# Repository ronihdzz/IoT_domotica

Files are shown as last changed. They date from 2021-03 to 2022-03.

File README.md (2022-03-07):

<hr>

## **Sistemas de domótica**
#### Autor: David Roni Hernández Beltrán
<hr>

Explicación del proyecto en español:

(https://www.youtube.com/watch?v=UfCgMUs2OLo)

Explicación del proyecto en ingles:

(https://www.youtube.com/watch?v=xrW_T7PZulM)

### **Menu**

* [1) Prerrequisitos](#1-prerrequisitos)
    * [1.1) Materiales](#11-materiales)
    * [1.2) Instalacion de paquetes de python](#12-instalacion-de-paquetes-de-python)

* [2) Funcionamiento](#2-funcionamiento)

    * [2.0) Explicacion detallada](PlaneacionSistemaDomotica.pdf)
    * [2.1) Explicacion breve](#21-explicacion-breve)
    * [2.2) Explicacion del sofware del proyecto](#22-explicacion-del-sofware-del-proyecto)
        * [2.2.1) Sistema de deberes](#221-sistema-de-deberes)
          * [2.2.1.1) Crear un deber](#2211-crear-un-deber)
          * [2.2.1.2) Cambiar el tamano y la posicion del texto de los deberes](#2212-cambiar-el-tamano-y-la-posicion-del-texto-de-los-deberes)
          * [2.2.1.3) Eliminar deberes cumplidos](#2213-eliminar-deberes-cumplidos)

        * [2.2.2) Sistema de administracion de alarmas](#222-sistema-de-administracion-de-alarmas)
          * [2.2.2.1) Crear una alarma](#2221-crear-una-alarma)
          * [2.2.2.2) Editar una alarma](#2222-editar-una-alarma)
          * [2.2.2.3) Eliminar una alarma](#2223-eliminar-una-alarma)
          * [2.2.2.4) Desactivar y activar una alarma](#2224-desactivar-y-activar-una-alarma)
          * [2.2.2.5) Hora de sonar de la alarma](#2225-hora-de-sonar-de-la-alarma)
          * [2.2.2.6) Establecer una cancion de tu elecccion en una alarma](#2226-establecer-una-cancion-de-tu-elecccion-en-una-alarma)

        * [2.2.3) Sistema de control](#223-sistema-de-control)
          * [2.2.3.1) Ver el dia la hora y la temperatura](#2231-ver-el-dia-la-hora-y-la-temperatura)
          * [2.2.3.2) Prendido manual y automatico de los objetos led RGB y ventilador](#2232-prendido-manual-y-automatico-de-los-objetos-led-rgb-y-ventilador)
            * [2.2.3.2.1) Funcionamiento del control manual y control automatico](#22321-funcionamiento-del-control-manual-y-control-automatico)
            * [2.2.3.2.2) Restricciones del control manual y control automatico](#22322-restricciones-del-control-manual-y-control-automatico)
            * [2.2.3.2.3) Prender y apagar manualmente el led RGB](#22323-prender-y-apagar-manualmente-el-led-rgb)
            * [2.2.3.2.4) Prender y apagar manualmente el ventilador](#22324-prender-y-apagar-manualmente-el-ventilador)
            * [2.2.3.2.5) Prender y apagar automaticamente el led RGB](#22325-prender-y-apagar-automaticamente-el-led-rgb)
            * [2.2.3.2.6) Prender y apagar automaticamente el ventilador](#22326-prender-y-apagar-automaticamente-el-ventilador)
          * [2.2.3.3) Cambiar el color del led RGB](#2233-cambiar-el-color-del-led-rgb)
          * [2.2.3.4) Detector de incendios](#2234-detector-de-incendios)

        * [2.2.4) Datos del programador](#224-datos-del-programador)

    * [2.3) Circuitos del proyecto](#23-circuitos-del-proyecto)

* [3) Ensamble del proyecto](#3-ensamble-del-proyecto)
    * [3.1) Paso 1](#31-paso-1)
    * [3.2) Paso 2](#32-paso-2)
    * [3.3) Paso 3](#33-paso-3)
    * [3.4) Paso 4](#34-paso-4)
    * [3.5) Paso 5](#35-paso-5)
    * [3.6) Paso 6(opccional)](#36-paso-6opccional)

* [4) Posibles errores](#4-posibles-errores)

* [5) Fuentes de informacion](#5-fuentes-de-informacion)

<hr>

## **1) Prerrequisitos**
<div class="myWrapper" markdown="1" align="center">

[Regresar al menu principal](#menu)
</div>

<hr>

A continuación se enlistan los prerrequisitos para poder ejecutar el proyecto:

### **1.1) Materiales**
<div class="myWrapper" markdown="1" align="center">

[Regresar al menu principal](#menu)
</div>

* 1-. Una computadora o...
  * Una rasberry pi y una monitor
  * Una rasberry pi y una tablet
  * Una rasberry pi y celular

<!--style="margin-left:auto;margin-right:auto;width:100%;"-->
<div style="text-align: center;">
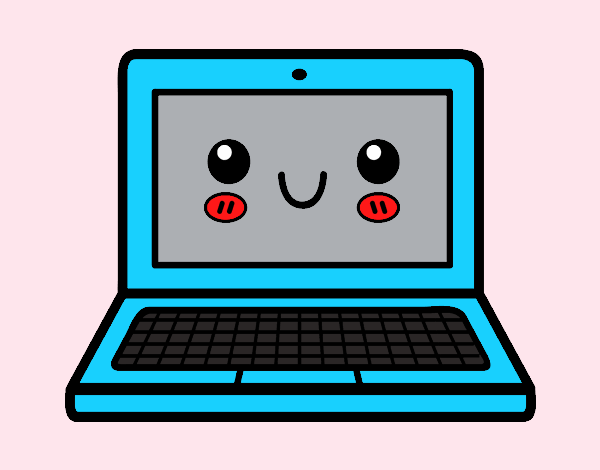
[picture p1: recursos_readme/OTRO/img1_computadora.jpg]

</div>

<!--style="margin-left:auto;margin-right:auto;width:100%;"-->
<div style="text-align: center;">
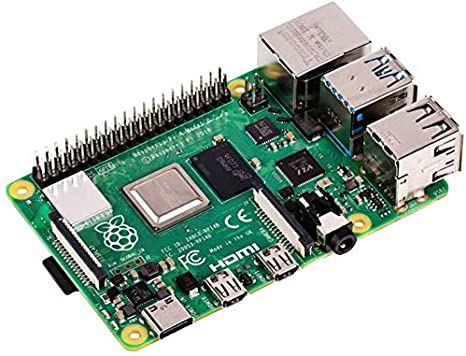
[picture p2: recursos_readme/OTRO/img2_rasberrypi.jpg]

</div>

* 2-. Un modulo adaptador serie usb a serial, yo recomiendo el: **convertidor USB Serial FTDI TTL FT232R**

<!--style="margin-left:auto;margin-right:auto;width:100%;"-->
<div style="text-align: center;">
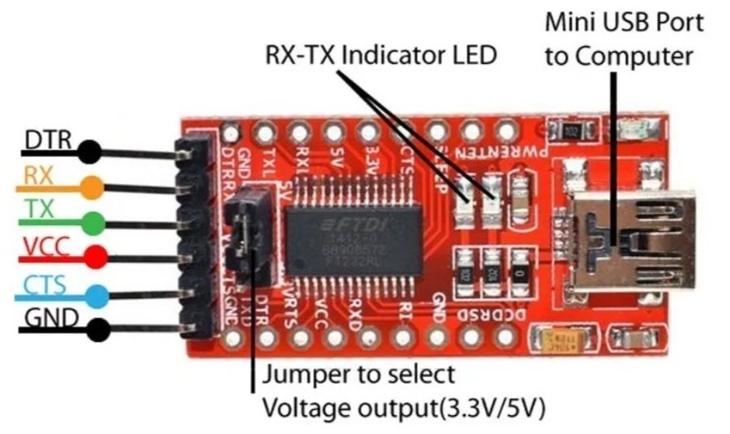
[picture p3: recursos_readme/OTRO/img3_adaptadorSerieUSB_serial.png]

</div>

* 3-. Un modulo bluetooth hc-05

<!--style="margin-left:auto;margin-right:auto;width:100%;"-->
<div style="text-align: center;">
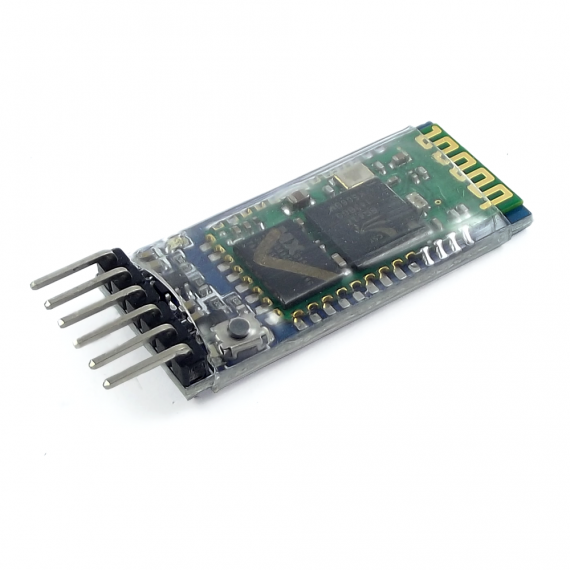
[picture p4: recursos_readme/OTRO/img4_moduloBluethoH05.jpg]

</div>

* 4-. Un cable USB a mini USB( para conectar el adaptador convertidor USB Serial FTDI TTL FT232R a un puerto usb de la rasberry o un puerto usb de la  computadora)
<!--style="margin-left:auto;margin-right:auto;width:100%;"-->
<div style="text-align: center;">
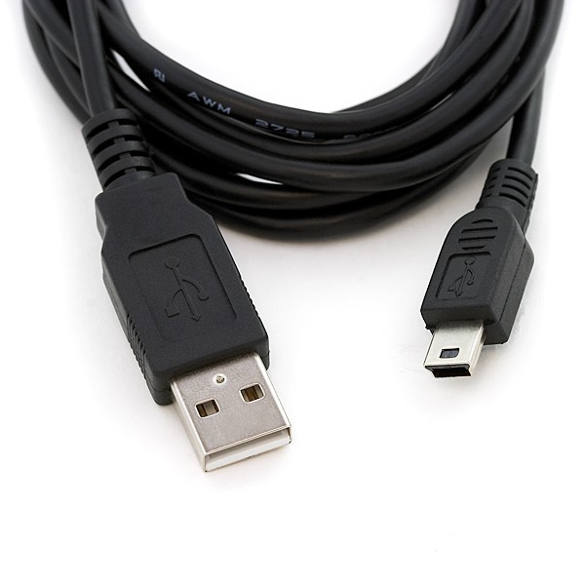
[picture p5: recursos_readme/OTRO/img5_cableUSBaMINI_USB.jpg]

</div>

* 5-. Un led RGB de preferencia el **sensor led RGB módulo KY-016**

<!--style="margin-left:auto;margin-right:auto;width:100%;"-->
<div style="text-align: center;">
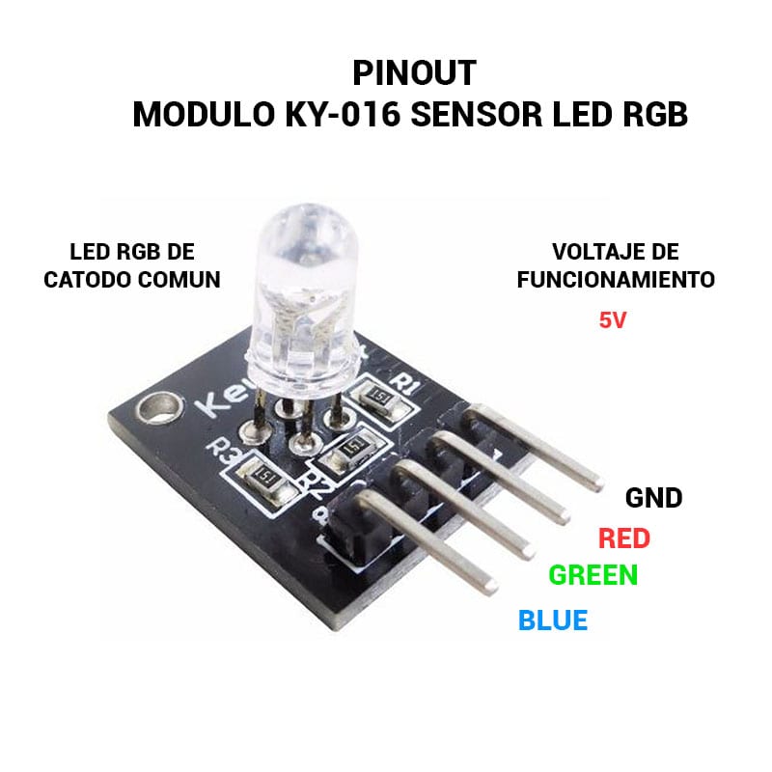
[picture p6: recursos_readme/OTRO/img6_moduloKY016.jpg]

</div>

* 6-. Un sensor de temperatura módulo KY-013

<!--style="margin-left:auto;margin-right:auto;width:100%;"-->
<div style="text-align: center;">
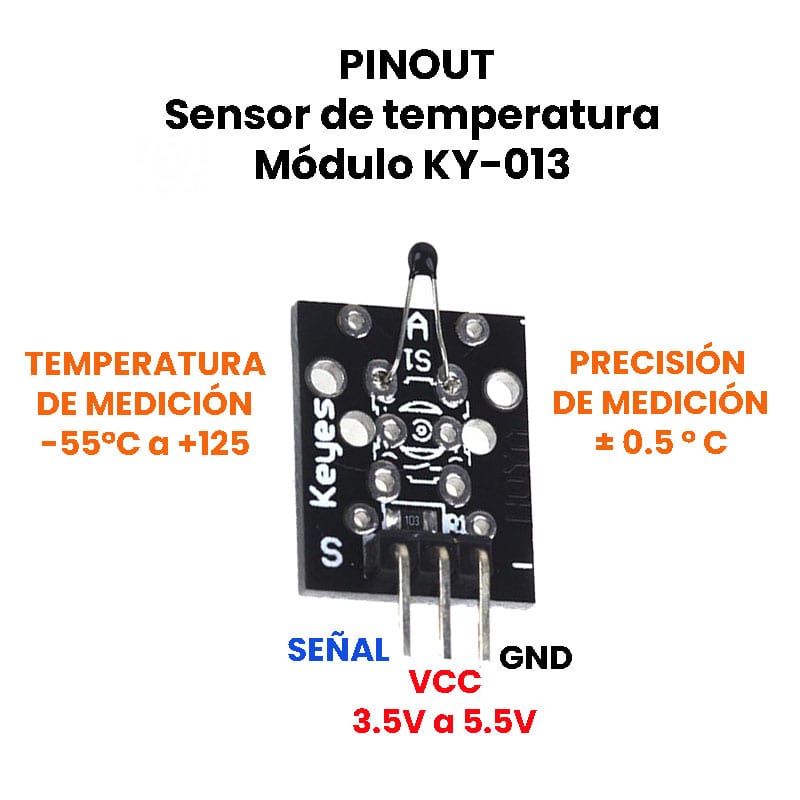
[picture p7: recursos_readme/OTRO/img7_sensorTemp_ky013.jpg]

</div>

* 7-. Un sensor de flama módulo KY-026 

<!--style="margin-left:auto;margin-right:auto;width:100%;"-->
<div style="text-align: center;">
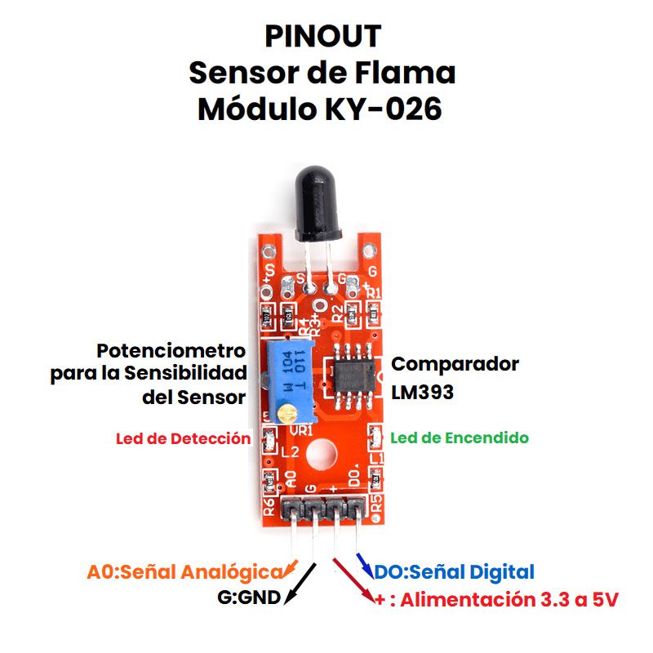
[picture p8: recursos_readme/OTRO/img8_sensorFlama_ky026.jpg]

</div>

* 8-. Un sensor de sonido módulo KY-037 

<!--style="margin-left:auto;margin-right:auto;width:100%;"-->
<div style="text-align: center;">
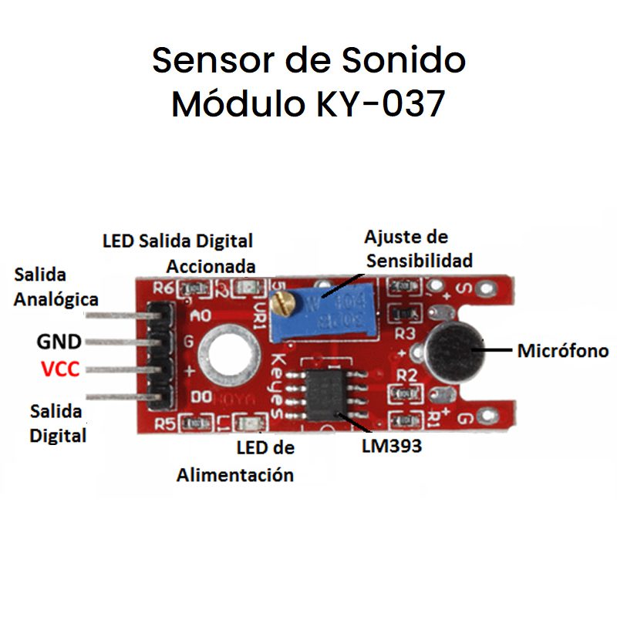
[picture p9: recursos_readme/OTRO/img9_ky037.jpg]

</div>

* 9-. Un módulo relevador 5V KY-019

<!--style="margin-left:auto;margin-right:auto;width:100%;"-->
<div style="text-align: center;">
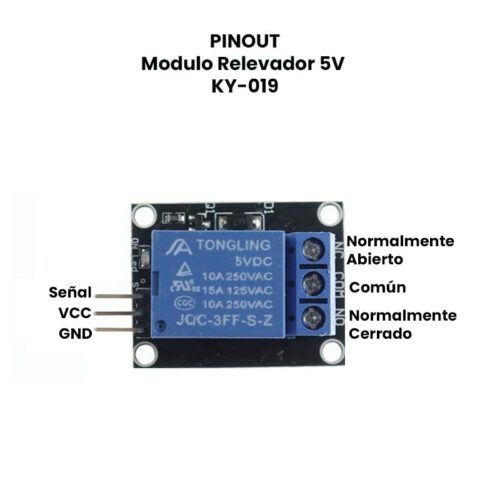
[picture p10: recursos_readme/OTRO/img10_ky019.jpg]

</div>

* 10-. Un arduino nano con su cable

<!--style="margin-left:auto;margin-right:auto;width:100%;"-->
<div style="text-align: center;">
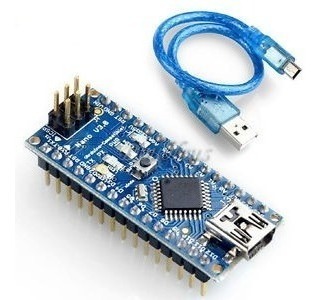
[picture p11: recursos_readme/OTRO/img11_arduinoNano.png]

</div>

* 11-. Un esp-32 nodemcu Micro Usb

<!--style="margin-left:auto;margin-right:auto;width:100%;"-->
<div style="text-align: center;">
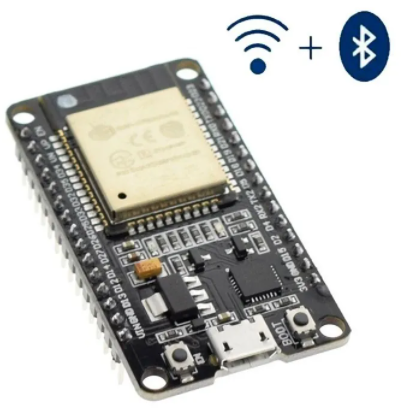
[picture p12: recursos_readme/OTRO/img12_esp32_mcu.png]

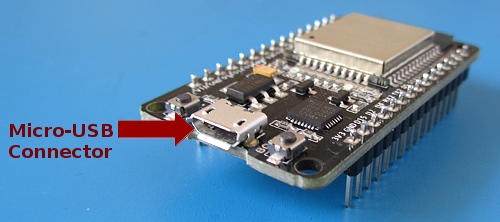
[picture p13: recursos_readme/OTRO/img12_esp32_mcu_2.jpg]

</div>

* 12-. Un cargador de celular con 5 volts de salida y minimo 1 A de corriente cuyo cable tambien permita la transmisión de datos  (para alimentar al esp32 y cargar los programas)

<!--style="margin-left:auto;margin-right:auto;width:100%;"-->
<div style="text-align: center;">
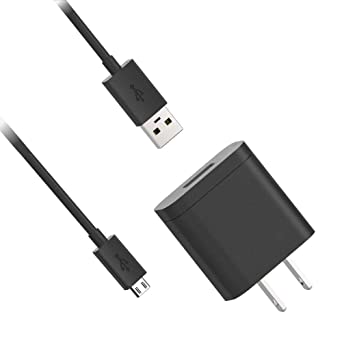
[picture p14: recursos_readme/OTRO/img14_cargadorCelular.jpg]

</div>

* 13-. Alambre de diferentes colores calibre 22(para conexiones en la protoboard) o jumpers macho, pero preferiblemente alambres

<!--style="margin-left:auto;margin-right:auto;width:100%;"-->
<div style="text-align: center;">
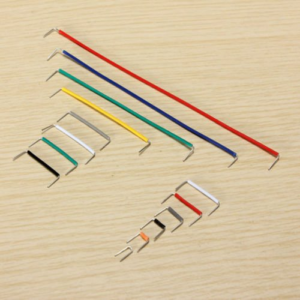
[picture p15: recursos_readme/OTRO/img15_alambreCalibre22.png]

</div>

* 14-. Dos protoboards

<!--style="margin-left:auto;margin-right:auto;width:100%;"-->
<div style="text-align: center;">
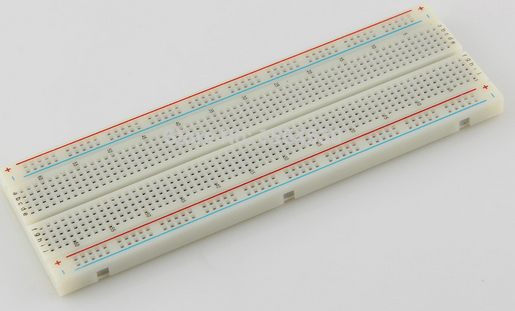
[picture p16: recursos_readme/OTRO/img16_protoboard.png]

</div>

<hr>

### **1.2) Instalacion de paquetes de python**
<div class="myWrapper" markdown="1" align="center">

[Regresar al menu principal](#menu)
</div>

<hr>

Sofware que debera tener instalado la rasberry pi o la computadora:

  * Python 3 instalado 
  * La herramienta de gestión de paquetes pip3
  * Una vez cumplidos las dos anteriores instalaciones, entonces deberan instalarse los paquetes de python que vienen en el requirements.

    A continuación se muestra como poder instalar los paquetes de python que vienen en el requirements:

    * Sistema operativo Rasbian(el que por default viene instalado en la rasberry pi)

      * Instalando herramientas de pyqt5 para poder ejecutar mi programa y tambien para que el codigo fuente de este pueda ser facilmente  modificado:
            <pre>
              <code>
                sudo apt update
                sudo apt install python3-pyqt5
                sudo apt install pyqt5-dev-tools
                sudo apt-get install qtcreator
              </code>
            </pre>

      * Instalando  pyserial
            <pre>
              <code>
                pip3 install pyserial
              </code>
            </pre>

      * Instalando  pygame
            <pre>
              <code>
                pip3 install pygame
              </code>
            </pre>

      * Instalando  mutagen
            <pre>
              <code>
                pip3 install mutagen
              </code>
            </pre>

    * Sistema operativo windows

      * Instalando herramientas de pyqt5 para poder ejecutar mi programa y tambien para que el codigo fuente de este pueda ser facilmente  modificado:
            <pre>
              <code>
                pip3 install PyQt5
                pip3 install PyQt5-tools
              </code>
            </pre>

      * Instalando  pyserial
            <pre>
              <code>
                pip3 install pyserial
              </code>
            </pre>

      * Instalando  pygame
            <pre>
              <code>
                pip3 install pygame
              </code>
            </pre>

      * Instalando  mutagen
            <pre>
              <code>
                pip3 install mutagen
              </code>
            </pre>

<hr> 

## **2) Funcionamiento** 

### **2.1) Explicacion breve** 
<div class="myWrapper" markdown="1" align="center">

[Regresar al menu principal](#menu)
</div>

<hr>

Mi proyecto consiste en un pequeño sistema de domótica el cual es administrado por una interfaz gráfica de escritorio la cual es capaz de hacer lo siguiente: 

*  Controlar el prendido y el apagado de un foco RGB, asi como el color al que este prende entre una variedad de 7 posibles colores (blanco, verde,amarillo, rojo, magenta, azul, cian)
*  Controlar el prendido y el apagado de un ventilador 
*  Avisar al usuario cuando se detecte un  incendio
*  Permitir la programación de alarmas.
*  Ofrecer un sistema de administración de deberes.

Para ver una explicación mas detallada de todo lo que puede hacer este proyecto, puedes leer el siguiente pdf:
[Sistema de domotica de Roni Hernandez explicado detalladamente](PlaneacionSistemaDomotica.pdf)

### **2.2) Explicacion del sofware del proyecto** 
<div class="myWrapper" markdown="1" align="center">

[Regresar al menu principal](#menu)
</div>

A continuación, se adjuntará una imagen de mi sistema de domótica y una breve explicación de cada apartado de ella:

<!--style="margin-left:auto;margin-right:auto;width:100%;"-->
<div style="text-align: center;">
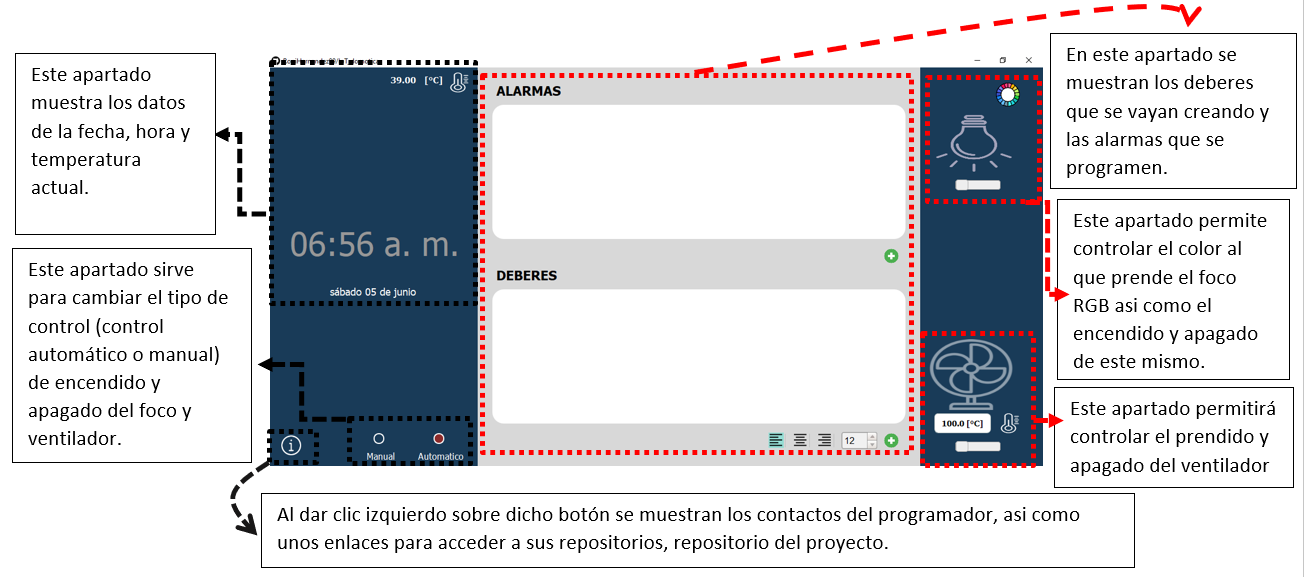
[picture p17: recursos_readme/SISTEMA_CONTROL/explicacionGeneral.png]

</div>

Explicado lo anterior ahora proseguiré a explicar de una forma más detallada cada función del sistema de domótica:

<hr>

### **2.2.1) Sistema de deberes**
<div class="myWrapper" markdown="1" align="center">

[Regresar al menu principal](#menu)
</div>

<hr>

La GUI permite  agregar deberes con la finalidad de que cada que vez que se termine un deber agregado, se  pueda eliminar de la lista de deberes, y sentir esa satisfacción personal de eliminar los deberes cada vez que se van cumpliendo.

### **2.2.1.1) Crear un deber**
<div class="myWrapper" markdown="1" align="center">

[Regresar al menu principal](#menu)
</div>

* Dar clic izquierdo sobre el botón redondo de color verde con una cruz blanca dentro el cual se encuentra debajo de la esquina inferior derecha del rectangulo blanco que se encuentra debajo de la leyenda 'DEBERES'
* Posteriormente se aparecera una rectangulo blanco, ahi debera escribirse el deber.
* Si se desea crear otro deber se deberan repetir los pasos antes mencionados.

En el siguiente ejemplo se crearan 3 deberes:
  * correr en la mañana
  * hacer tarea
  * estudiar en la noche

<div style="text-align: center;">
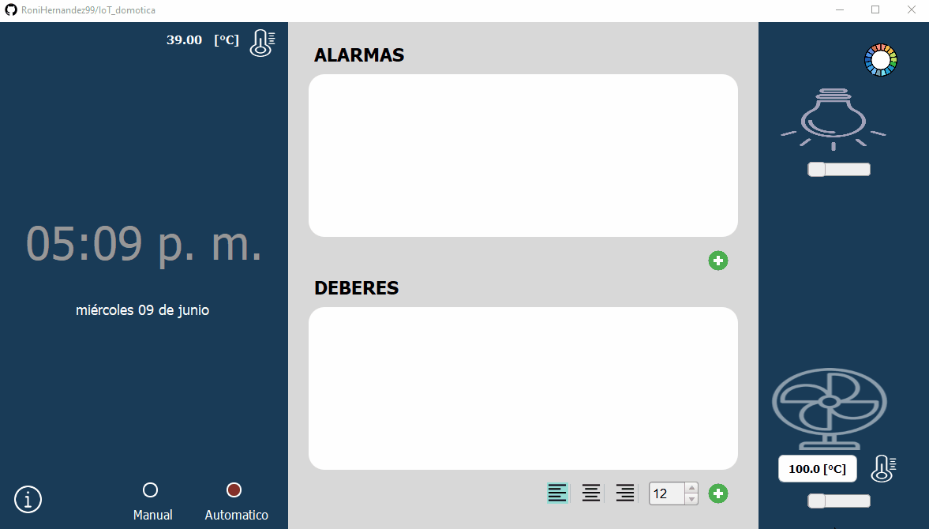
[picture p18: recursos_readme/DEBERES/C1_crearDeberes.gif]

</div>

<!--![Creacion de deberes](recursos_readme/DEBERES/C1_crearDeberes.gif)-->

### **2.2.1.2) Cambiar el tamano y la posicion del texto de los deberes**
<div class="myWrapper" markdown="1" align="center">

[Regresar al menu principal](#menu)
</div>

* Si se desea cambiar el tamaño de la letra de los deberes se deberá modificar el valor numérico del rectángulo que se encuentra a lado izquierdo del boton que sirve para agregar deberes:

<div style="text-align: center;">
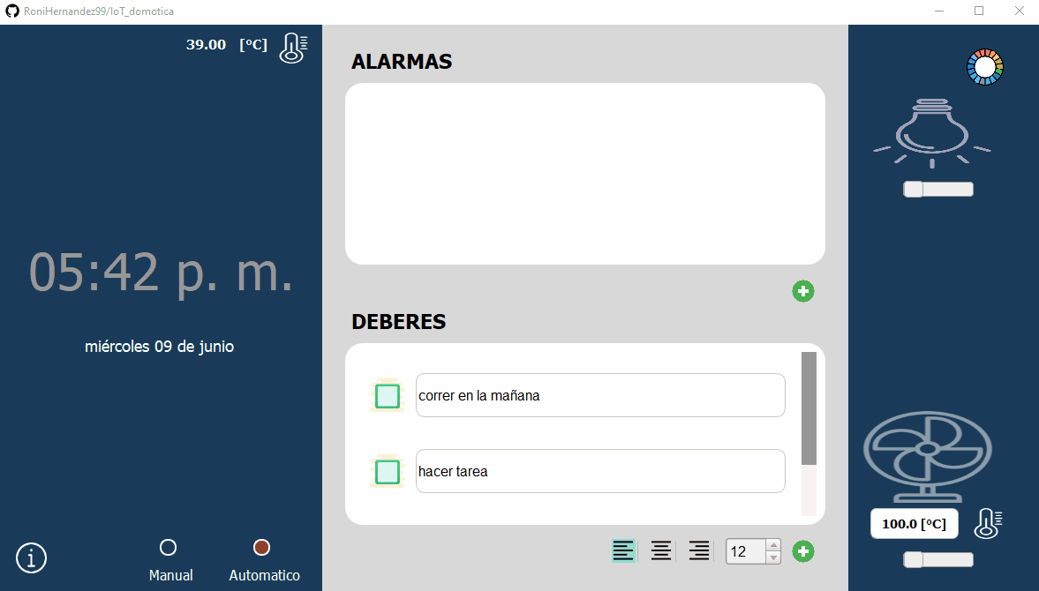
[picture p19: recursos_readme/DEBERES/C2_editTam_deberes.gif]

</div>

<!--![Editar la posicion el tamaño de los deberes](recursos_readme/C2_editTam_deberes.gif)-->

* Si se desea cambiar la posición del texto de los deberes, se deberá dar clic sobre el icono respectivo de alineación:

<div style="text-align: center;">
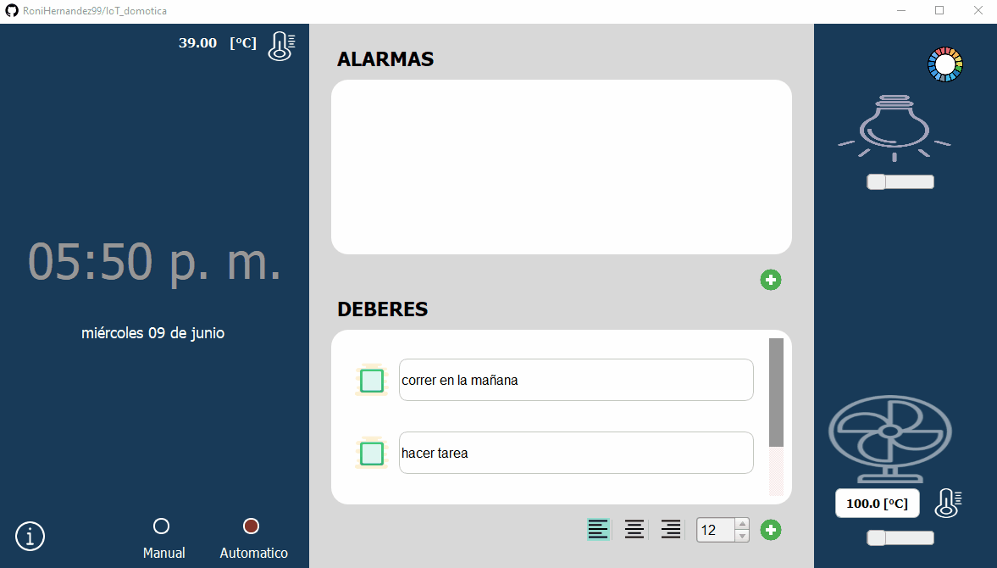
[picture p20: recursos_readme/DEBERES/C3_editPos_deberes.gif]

</div>

<!--![Editar la posicion  de los deberes](recursos_readme/C3_editPos_deberes.gif)-->

### **2.2.1.3) Eliminar deberes cumplidos**

<div class="myWrapper" markdown="1" align="center">

[Regresar al menu principal](#menu)
</div>

* Para eliminar un deber  ya sea por que se cumplio o por que hubo una equivocacion al crearlo se debera hacer lo siguiente:
  * Dar clic izquierdo sobre el cuadrado que se encuentra al lado izquierdo del deber que se desea eliminar
  * Al hacer el paso anterior  se  desplegara un cuadro de dialogo, el cual preguntara si efectivamente se desea eliminar el deber, se debera dar clic izquierdo sobre la opccion 'si'.

En el siguiente ejemplo se eliminaran 2 deberes:
  * correr en la mañana
  * hacer tarea

<div style="text-align: center;">
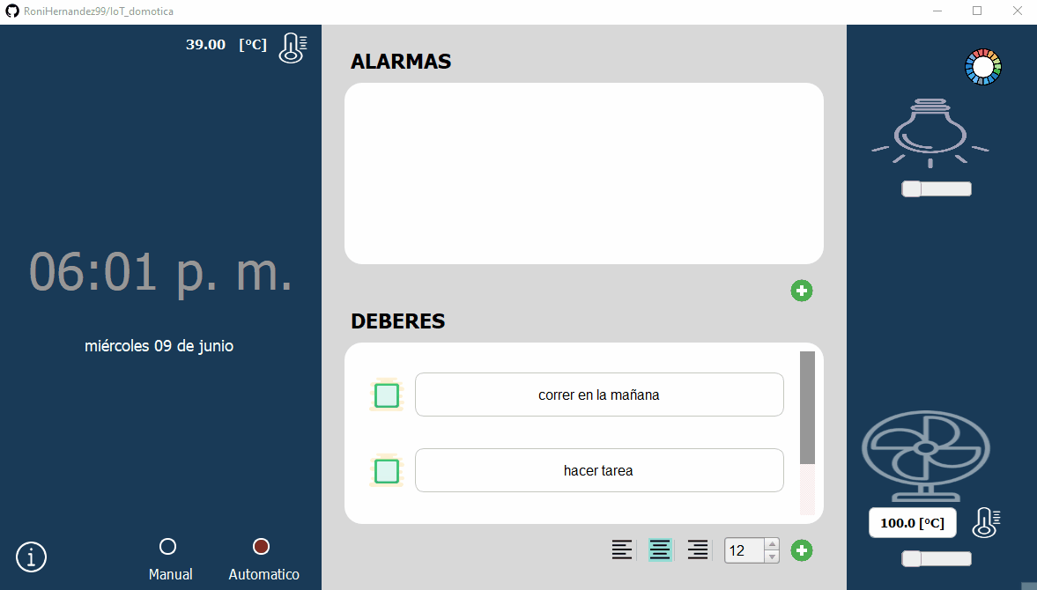
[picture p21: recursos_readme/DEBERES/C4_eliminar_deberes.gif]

</div>

<!--![Eliminar deberes](recursos_readme/C4_eliminar_deberes.gif)-->

<hr> 

### **2.2.2) Sistema de administracion de alarmas**
<div class="myWrapper" markdown="1" align="center">

[Regresar al menu principal](#menu)
</div>

<hr>

El sistema de alarmas permite  agendar  alarmas tal y como lo hace un teléfono celular, es decir permitirá:

•	Asignar un nombre a la alarma

•	Escoger la canción que tocará la alarma al ejecutarse, entre una lista de canciones que ofrecerá el programa de forma default o canciones que el usuario puede importar desde su administrador de archivos.

•	Escoger la hora y el día o los días en las cuales la alarma debe sonar.

•	Crear como máximo un numero de 50 alarmas.

•	Editar alarmas que ya fueron creadas.

•	Eliminar alarmas que ya fueron creadas.

•	Desactivar o activar una o varias alarmas.

A continuacion se proseguira a explicar de forma mas detallada 

### **2.2.2.1) Crear una alarma**
<div class="myWrapper" markdown="1" align="center">

[Regresar al menu principal](#menu)
</div>

* Dar clic izquierdo sobre el botón redondo de color verde con una cruz blanca dentro, el boton se encuentra debajo de la esquina inferior derecha del rectangulo blanco que se encuentra debajo de la leyenda 'ALARMAS'

* Posteriormente se aparecera una ventana en la se deben ingresar los datos de la alarma que se desea crear

<div style="text-align: center;">
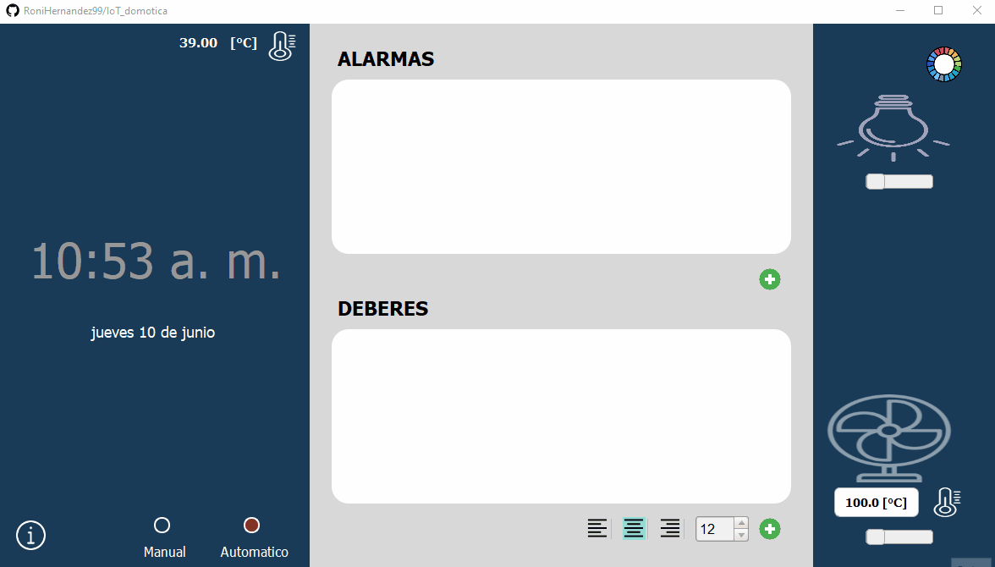
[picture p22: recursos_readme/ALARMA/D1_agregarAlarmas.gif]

</div>

* Antes de dar un ejemplo de como crear una alarma primero  proseguire a explicar cada apartado de la ventana que se abrio al hacer el paso anterior.

<div style="text-align: center;">
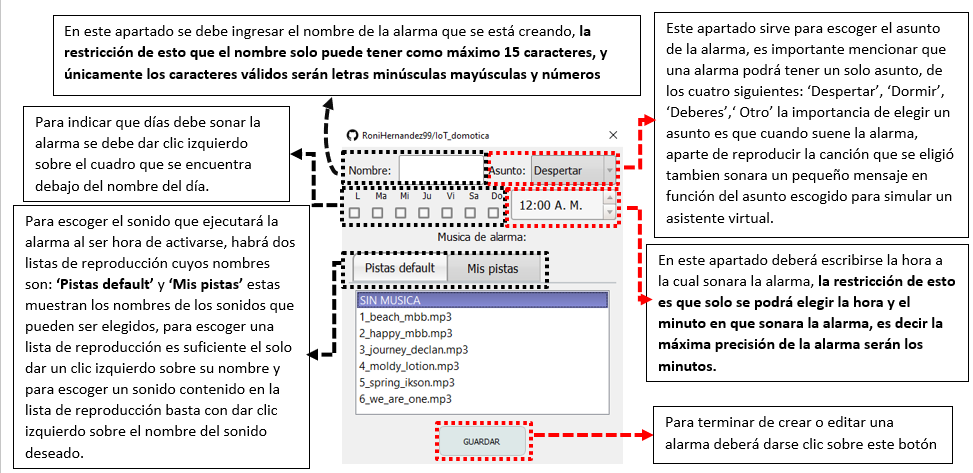
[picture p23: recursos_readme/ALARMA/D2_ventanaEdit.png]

</div>

* Una vez explicada la ventana anterior, proseguire a dar un ejemplo de como crear una alarma con las siguientes caracteristicas:

  * Nombre de la alarma: 'horaEscuela' 

  * Dia en los cuales sonar: lunes,martes,miércoles,jueves y viernes
  
  * Hora a la que sonara: 4:45 am  
  
  * Asunto: Despertar 
  
  * Cancion: Sera una de las que traer por default el programa

<div style="text-align: center;">
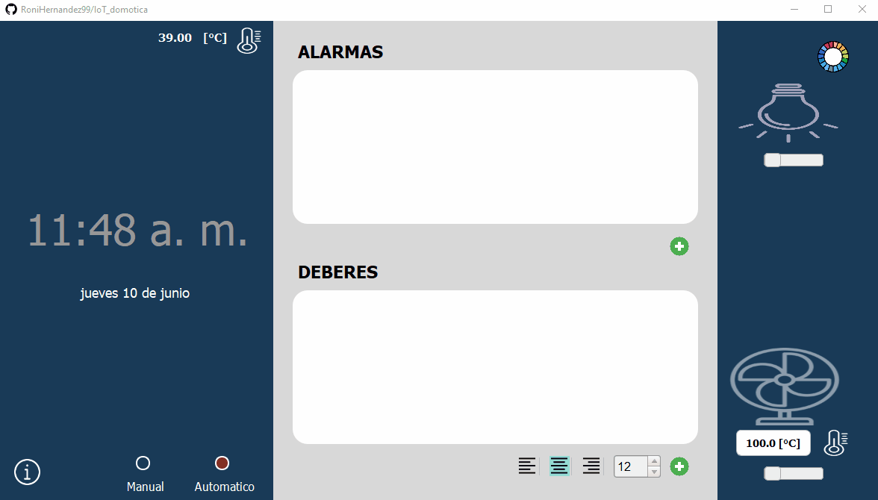
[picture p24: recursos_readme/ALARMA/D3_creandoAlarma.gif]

</div>

Una vez hecho lo anterior se podrá observar que apareceran los datos de la alarma creada dentro del   rectangulo blanco que se encuentra debajo de la leyenda 'ALARMAS', y eso ocurre por que todas las alarmas que se creen se mostraran ahi para que puedan ser facilmente editadas visualizadas o eliminadas.
 
<div style="text-align: center;">
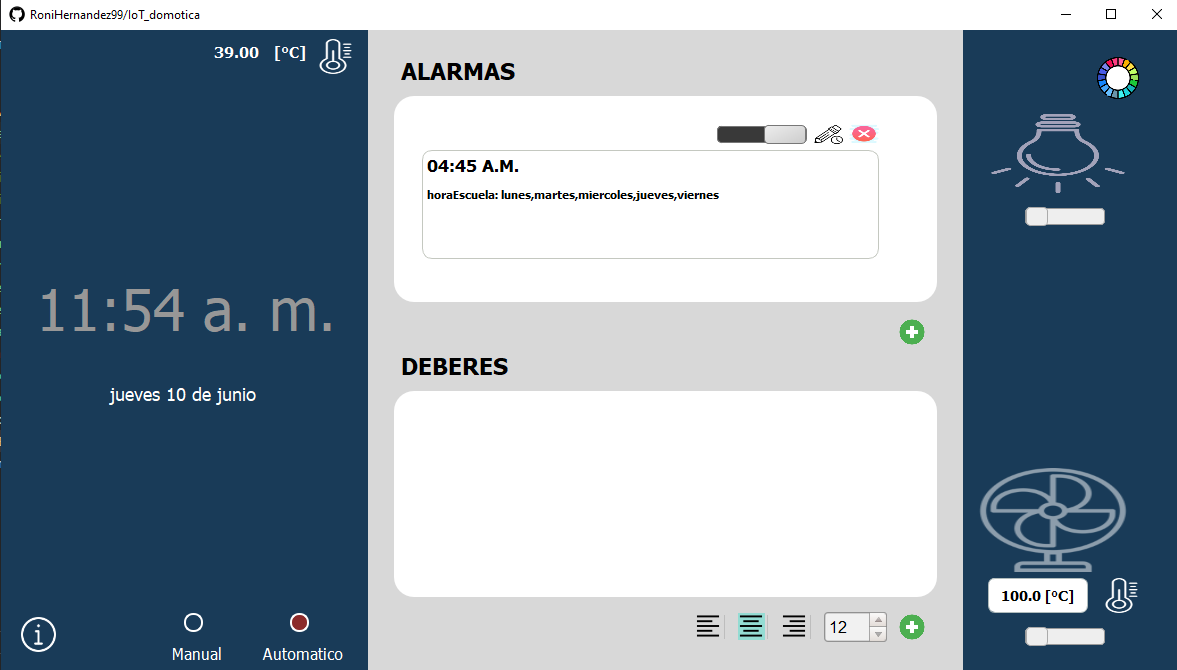
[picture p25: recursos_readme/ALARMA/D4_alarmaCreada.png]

</div>

A continuacion se crearan 2 alarmas mas para que se pueda apreciar de mejor manera lo anterior mencionado:

<div style="text-align: center;">
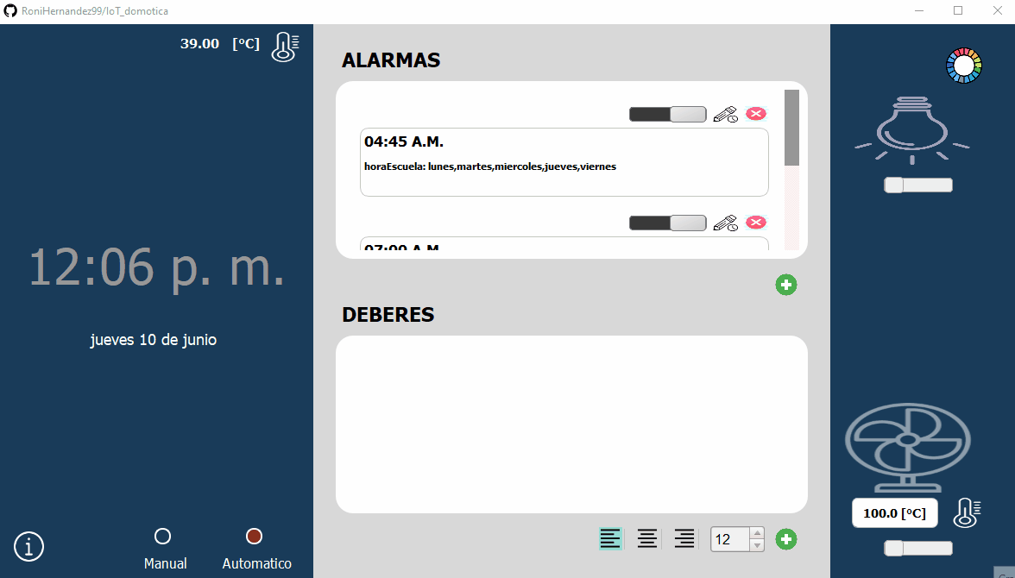
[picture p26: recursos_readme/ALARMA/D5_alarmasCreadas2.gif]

</div>

Es importante resaltar que los datos claves que se muestran de cada alarma creada, son los siguientes:

<div style="text-align: center;">
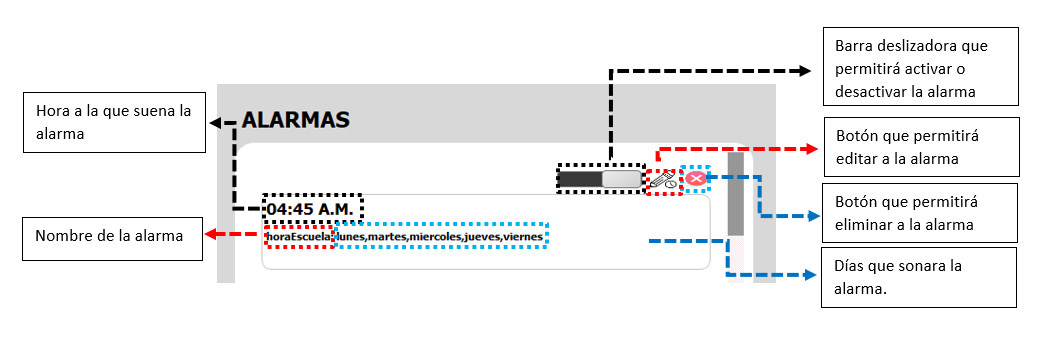
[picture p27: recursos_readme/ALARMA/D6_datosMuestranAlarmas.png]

</div>

### **2.2.2.2) Editar una alarma**
<div class="myWrapper" markdown="1" align="center">

[Regresar al menu principal](#menu)
</div>

Si se deseara editar una alarma, se debe dar clic izquierdo sobre el icono del lápiz que se encuentra en la esquina superior derecha de la alarma que se desea editar.

En el siguiente ejemplo se desea editar la alarma cuyo nombre es: **'irCorrer'** la cual suena los dias: **'sabado y domingo'** a las: **'6:45 am'**, los nuevos cambios que se desean hacer son los siguientes:
  * Que ahora suene a las: **'7:00 am'** los dias: **'sabado,domingo y lunes'** 

<div style="text-align: center;">
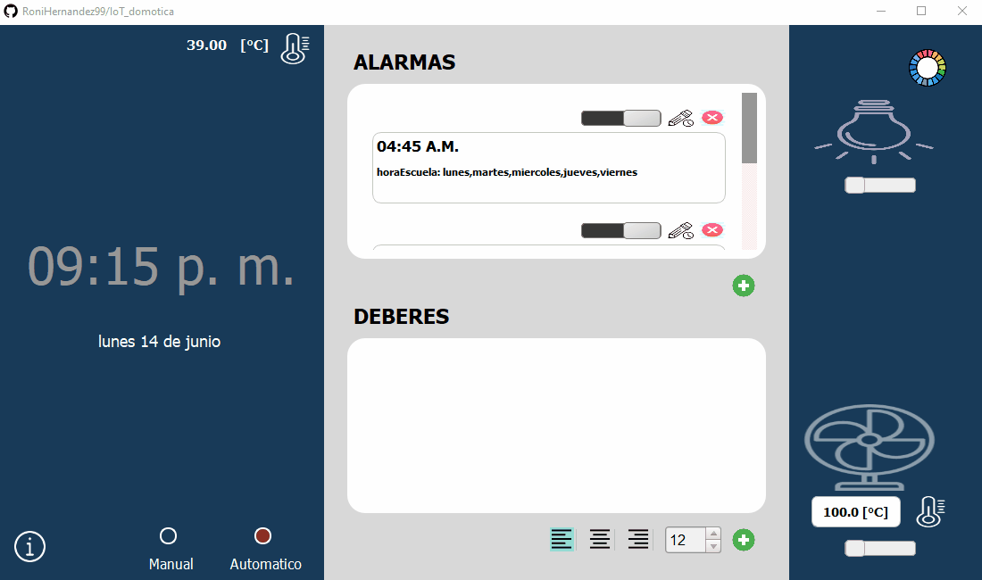
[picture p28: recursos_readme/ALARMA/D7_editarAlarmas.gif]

</div>

### **2.2.2.3) Eliminar una alarma**
<div class="myWrapper" markdown="1" align="center">

[Regresar al menu principal](#menu)
</div>

Si se desea eliminar una alarma, se deberá dar clic izquierdo sobre el icono del tache que se encuentra en la esquina superior derecha de la alarma que se desea eliminar.

En el siguiente ejemplo se desea  eliminar la alarma  **‘horaEscuela’**:

<div style="text-align: center;">
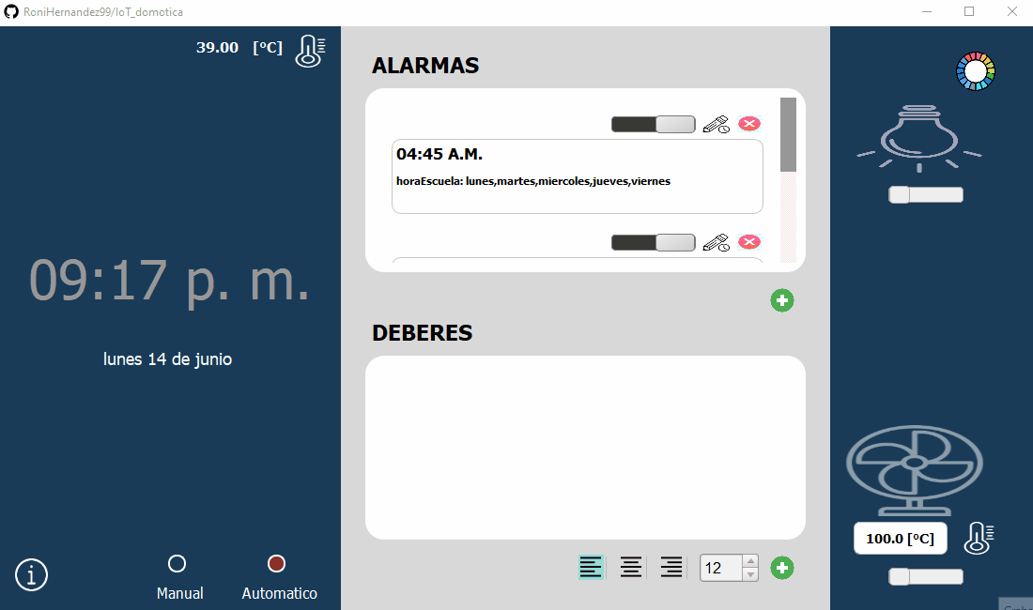
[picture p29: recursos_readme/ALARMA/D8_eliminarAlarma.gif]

</div>

### **2.2.2.4) Desactivar y activar una alarma**
<div class="myWrapper" markdown="1" align="center">

[Regresar al menu principal](#menu)
</div>

Si se deseara desactivar una alarma para que no suene, se deberá deslizar la barra deslizadora que se encuentra en su esquina superior derecha.

En la siguiente imagen se activa y desactiva la alarma cuyo nombre es: **'irCorrer'**

<div style="text-align: center;">
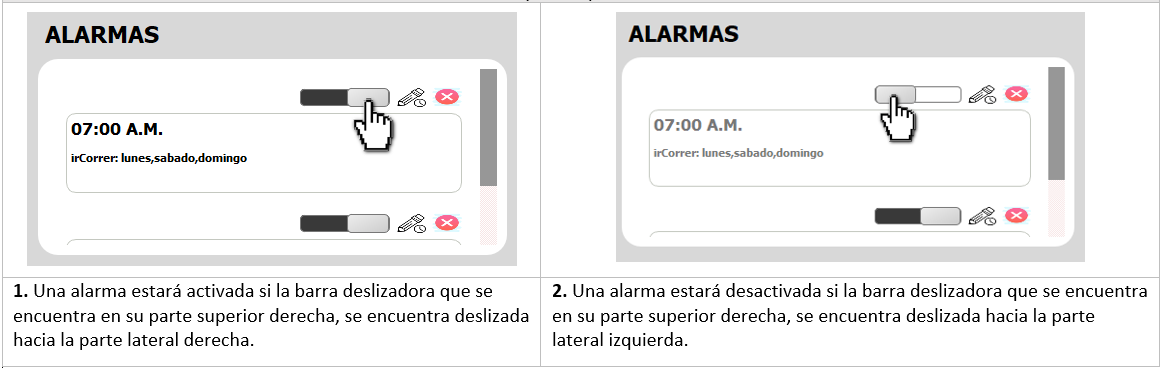
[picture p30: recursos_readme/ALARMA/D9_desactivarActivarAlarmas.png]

</div>

### **2.2.2.5) Hora de sonar de la alarma**
<div class="myWrapper" markdown="1" align="center">

[Regresar al menu principal](#menu)
</div>

¿Que pasa cuando es la hora de sonar de una alarma?

Se mostrará un cuadro emergente con únicamente dos datos de la alarma que está sonando: la hora a la que debe sonar y el nombre de la alarma

En el siguiente ejemplo se puede apreciar la alarma **'irDormir'**: se activo y para apagarla debera deslizarse la barra hasta el extremo derecho, tal y como se hace en un celular, cuando pasa eso, la ventana se cierra automaticamente.

<div style="text-align: center;">
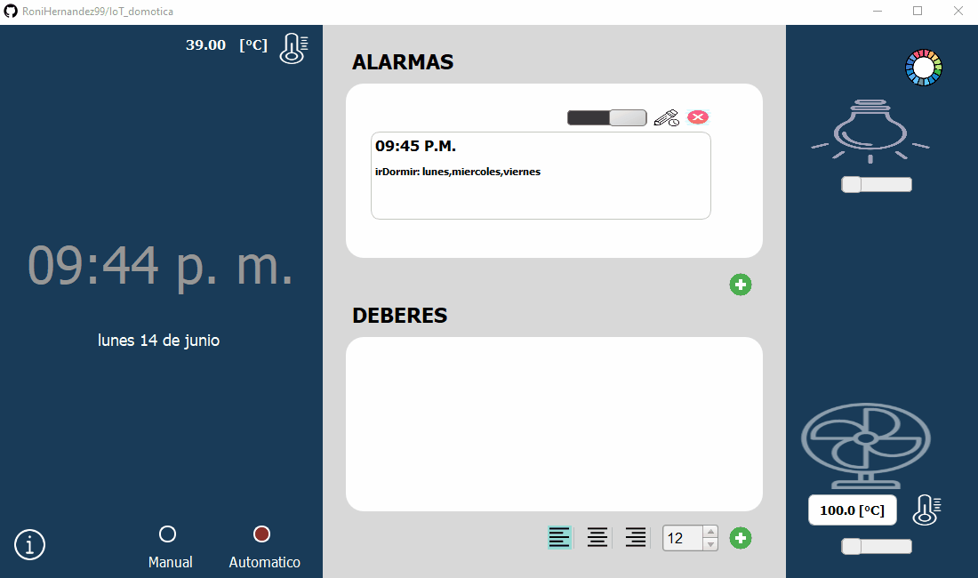
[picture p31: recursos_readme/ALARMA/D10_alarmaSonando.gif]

</div>

### **2.2.2.6) Establecer una cancion de tu elecccion en una alarma**
<div class="myWrapper" markdown="1" align="center">

[Regresar al menu principal](#menu)
</div>

¿Como establecer como canción de alarma una canción de mi eleccion?

El programa permite importar canciones en  la ventana que se abre cuando se esta creando una alarma o editando un alarma.Una vez abierta dicha ventana, para importar una cancion se deberan seguir los siguientes pasos:

* Primero deberá escogerse la lista de reproducción ‘Mis pistas’ dando clic izquierdo sobre el botón respectivo.

* Si no se ha agregado ninguna canción se vera una  lista de reproducción vacía pero en caso contrario 
se veran los nombres de las canciones ya importadas.

* Para agregar una canción se deberá dar clic sobre el botón de forma de carpeta, el cual al hacer clic sobre el, la GUI abrira el explorador de archivos el cual permite elegir la canción que se desea agregar desde la ubicación en donde se encuentre.

* Una vez escogida la canción se aparecera en la lista de reproducción lista para ser seleccionada.

<div style="text-align: center;">
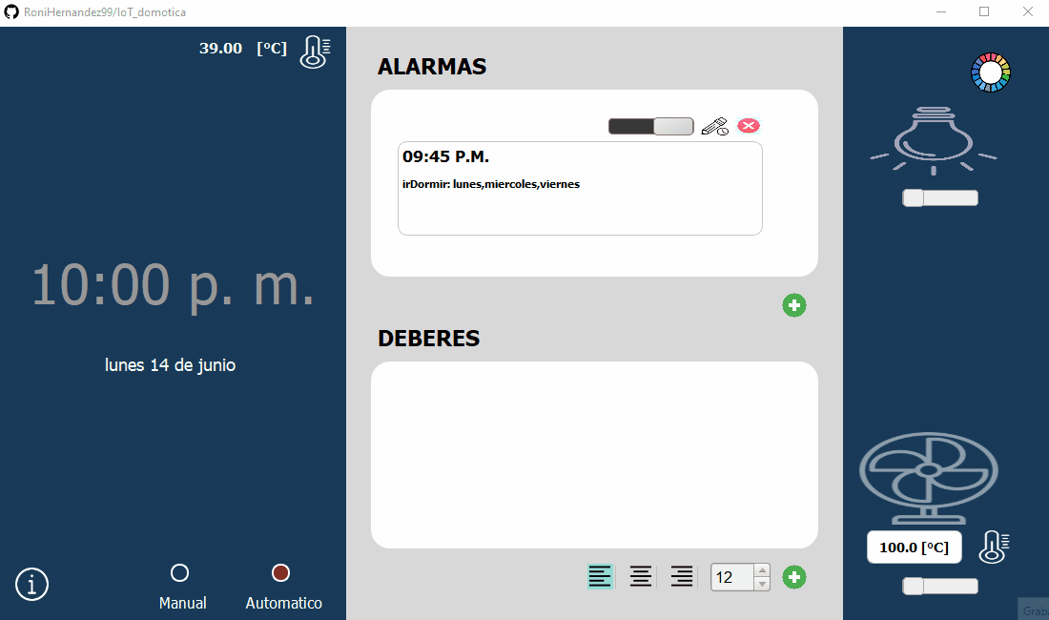
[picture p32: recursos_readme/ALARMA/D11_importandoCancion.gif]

</div>

<hr>

### **2.2.3) Sistema de control**
<div class="myWrapper" markdown="1" align="center">

[Regresar al menu principal](#menu)
</div>

<hr>

### **2.2.3.1) Ver el dia la hora y la temperatura**
<div class="myWrapper" markdown="1" align="center">

[Regresar al menu principal](#menu)
</div>

El sistema muestra  al usuario:

•	La fecha en la cual se encuentra (nombre del día, numero de día, nombre del mes y año)

•	La hora en la cual se encuentra (hora, minuto, AM/PM)

•	La temperatura actual a la que se encuentra. Es importante mencionar que la temperatura que muestra el programa  se actualiza  cada vez que el sistema detecta una variación de temperatura de +- 0.3 [°C]

<div style="text-align: center;">

</div>

### **2.2.3.2) Prendido manual y automatico de los objetos led RGB y ventilador**
<div class="myWrapper" markdown="1" align="center">

[Regresar al menu principal](#menu)
</div>

El programa ofrece dos modalidades para controlar el prendido y apagado de los objetos(ventilador y led RGB) las cuales son las siguientes:

  * Control automatico
  * Control manual 

### **2.2.3.2.1) Funcionamiento del control manual y control automatico**
<div class="myWrapper" markdown="1" align="center">

[Regresar al menu principal](#menu)
</div>

**¿Cómo funciona exactamente el control manual y el control automatico?**  

<table>
    <thead>
        <tr>
          <th >Dispositivo</th>
          <th colspan=2>Tipo de encendido y apagado</th>
        </tr>
        <tr >
            <th>  </th>
            <th > Automatico </th>
            <th> Manual</th>
        </tr>
    </thead>
    <tbody>
        <tr>
            <td> LED RGB </td>
            <td >Si se detecta un aplauso o un sonido similar, se prendera el LED RGB si se encontraba apagado, o se apagará si se encontraba prendido.</td>
            <td rowspan=2> Atreves de una barra deslizante que se encontrará inmersa en la GUI, el usuario podrá apagar o prender el objeto (led RGB o ventilador):
            <ol>
              <li>Si desliza la barra a la izquierda se apagará al objeto.</li>
              <li>Si desliza la barra a la derecha se prendera al objeto.</li>
            </ol>
</td>
       </tr>
        <tr>
             <td> VENTILADOR </td>
             <td>
            Si se detecta una temperatura mayor o igual a la que el usuario estableció se prendera el ventilador, en caso contrario se apagará.<br>
Mas adelante se explicará cómo se puede modificar  la temperatura a la cual prende el ventilador
            </td>
        </tr>
    </tbody>
</table>

### **2.2.3.2.2) Restricciones del control manual y control automatico**
<div class="myWrapper" markdown="1" align="center">

[Regresar al menu principal](#menu)
</div>

Es importante mencionar que los controles: automatico y manual no pueden funcionar al mismo tiempo, es decir: 

•	Si se elige controlar el prendido y apagado de los objetos de forma automática no se podrán controlar de forma manual, por el contrario, si se elige controlar el prendido y apagado de forma manual no se podrán controlar de forma automática por ende:
* Cuando se elige la modalidad manual, la GUI desbloquea a las barras deslizadoras que se encuentran abajo de la imagen del foco y ventilador, para que el usuario pueda manipularlas con el fin de prender o apagar el objeto que quiera.
* Cuando se elige la modalidad automatica la GUI, bloquea a las barras deslizadoras para que el usuario no pueda manipularlas, ya que los objetos solo podrán ser prendidos de forma automática. 

### **2.2.3.2.3) Prender y apagar manualmente el led RGB**
<div class="myWrapper" markdown="1" align="center">

[Regresar al menu principal](#menu)
</div>

**Instrucciones del prendido y apagado manual del led RGB**

*  Asegurarnos que se este en modalidad manual
*  Mover la barra deslizadora que se encuentra debajo de la imagen del foco, a la izquierda si se desea apagar el led RGB.
*  Mover la barra deslizadora que se encuentra debajo de la imagen del foco, a la derecha si se desea prender el led RGB.

<div style="text-align: center;">

</div>

### **2.2.3.2.4) Prender y apagar manualmente el ventilador**
<div class="myWrapper" markdown="1" align="center">

[Regresar al menu principal](#menu)
</div>

**Instruccioes del prendido manual del ventilador**

*  Asegurarnos que se este en modalidad manual
*  Mover la barra deslizadora que se encuentra debajo de la imagen del ventilador, a la izquierda si se desea apagar el ventilador.
*  Mover la barra deslizadora que se encuentra debajo de la imagen del ventilador, a la derecha si se desea prender el ventilador.

<div style="text-align: center;">

</div>

### **2.2.3.2.5) Prender y apagar automaticamente el led RGB**
<div class="myWrapper" markdown="1" align="center">

[Regresar al menu principal](#menu)
</div>

**Instrucciones del prendido y apagado automatico del led RGB**

*  Asegurarnos que se este en modalidad automatica.
*  Si el led RGB se encuentra apagado y se desea prender, se de debera aplaudir una sola vez, para que se prenda.
*  Si el led RGB se encuentra prendido y se desea apagar, se debera aplaudir una sola vez, para que se apague.

<div style="text-align: center;">

</div>

### **2.2.3.2.6) Prender y apagar automaticamente el ventilador**
<div class="myWrapper" markdown="1" align="center">

[Regresar al menu principal](#menu)
</div>

**Instruccioes del prendido automatico del ventilador**
*  Asegurarnos que se este en modalidad automatica.
*  Cersiorarse que la temperatura  a la cual se desea prender el ventilador sea la correcta, para este ejemplo se desea que se prenda el ventilador a partir de los 28 [°C].
*  Esperar a que la temperatura del dia sea mayor o igual a la temperatura establecida para que el programa mande a prender el ventilador de forma automatica.En el siguiente ejemplo se tocara al sensor de temperatura para que la temperatura que el registre aumente y asi se llegue o supere a la temperatura establecida y por ende se prenda el ventilador, despues se proseguira a dejar de tocar el sensor de temperatura y se podra apreciar como baja la temperatura registrada por el sensor y cuando esta sea menor a la establecida se podra visualizar como se manda a apagar el ventilador.

<div style="text-align: center;">

</div>

### **2.2.3.3) Cambiar el color del led RGB**
<div class="myWrapper" markdown="1" align="center">

[Regresar al menu principal](#menu)
</div>

El programa permite al usuario  cambiar el color con el que prende el led RGB entre una variedad de 7 posibles colores (blanco, verde, amarillo, rojo, magenta, azul, cian) siguiendo las siguientes instrucciones:

*  Dar clic izquierdo sobre el botón que se encuentra en la esquina superior derecha de la imagen del foco.
*  Dar clic izquierdo sobre el color de preferencia.
*  Posteriormente dar clic izquierdo sobre el texto con la leyenda de: 'Aplicar'

Es importante mencionar que:

•	Si se cambia el color del led RGB mientras este se encuentra apagado, no se visualizara el cambio de color hasta que el led RGB se prenda, es decir si se efectuará el cambio de color del led RGB pero como se encuentra apagado, no se podrá apreciar dicho cambio hasta que se prenda.

•	Si se cambia el color del led RGB mientras este esté prendido, se apreciara el cambio de color casi de una manera instantánea. 

<div style="text-align: center;">

</div>

### **2.2.3.4) Detector de incendios**
<div class="myWrapper" markdown="1" align="center">

[Regresar al menu principal](#menu)
</div>

El sistema de domótica siempre  esta  al pendiente de la aparición de fuego, y si detecta alguna flama esta le alertara al usuario a través de la GUI por medio de un sonido y un mensaje emergente.

Es importante mencionar que cuando se detecta fuego:
* Se bloquea el control automático y manual de los objetos
* No se podrá hacer nada en la GUI
* Si una alarma tiene que sonar no sonara ya que la prioridad es alertar al usuario de la presencia del fuego.

A continuación, se adjuntará un video de como reacciona el sistema ante la deteccion de fuego.

<div style="text-align: center;">

</div>

### **2.2.4) Datos del programador**
<div class="myWrapper" markdown="1" align="center">

[Regresar al menu principal](#menu)
</div>

El sistema de domótica ofrece un apartado en donde el usuario pueda ver los contactos del programador, es decir mis datos de contacto personales, tambien muestra un link de acceso al  repositorio de todo este proyecto, lo único que se tendrá que hacer es dar clic izquierdo sobre el icono con signo de exclamación e inmediatamente se desplegara una ventana con dichos datos.

A continuación de muestra como.

<!--style="margin-left:auto;margin-right:auto;width:100%;"-->
<div style="text-align: center;">

</div>

<hr>

### **2.3) Circuitos del proyecto**
<div class="myWrapper" markdown="1" align="center">

[Regresar al menu principal](#menu)
</div>

<hr>

Mi proyecto basicamente se divide en dos circuitos:

* El primer circuito se encarga de las siguientes cosas:
  * Avisarle a la rasberry pi cuando se detecte una flama de fuego
  * Avisarle a la rasberry pi cuando se detecte un ruido similar al de un aplauso
  * Adjuntarle a la rasberry pi la temperatura que se esta sensando
  * Avisarle al circuito 2 por medio de comunicación bluetooth cuando prender u apagar el ventilador
  * Avisarle al circuito 2 por medio de comunicación bluetooth cuando prender u apagar el led RGB
  * Avisarle al circuito 2 por medio de comunicación bluetooth con que color debe prender el led RGB

[Dar clic aqui para ver circuito de manera mas legible el circuito 1](HADWARE/circuitos/circuito_1.png)

<!--style="margin-left:auto;margin-right:auto;width:100%;"-->
<div style="text-align: center;">
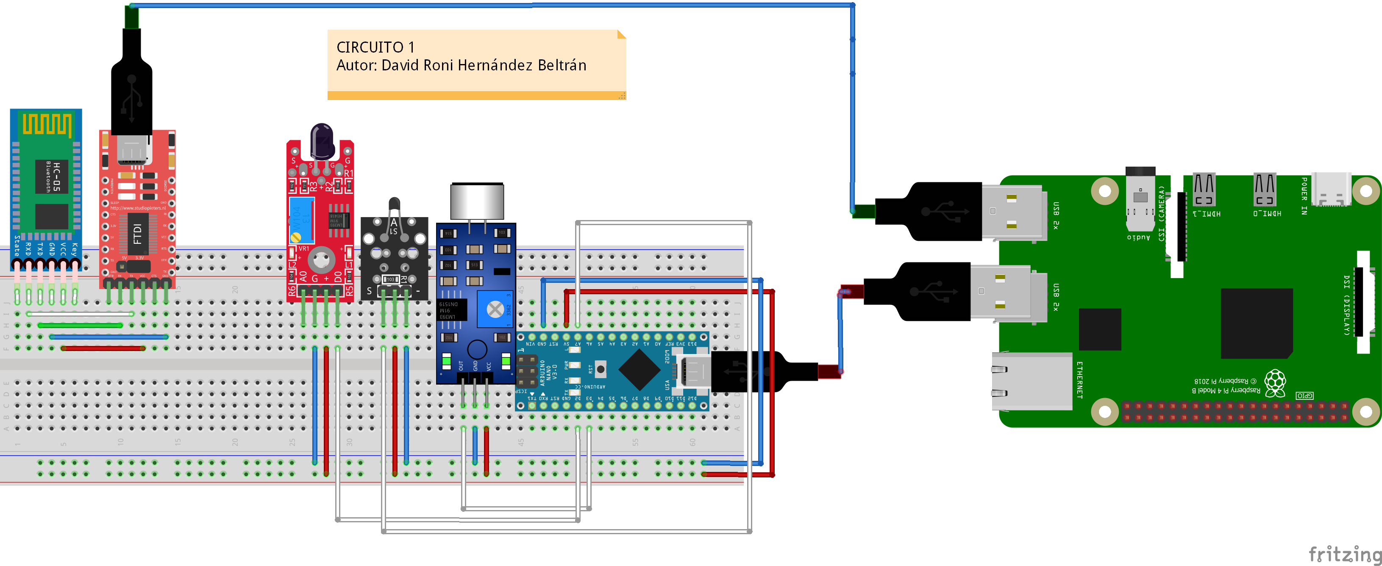
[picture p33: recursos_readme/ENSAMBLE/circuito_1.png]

</div>

* El segundo circuito se encarga de las siguientes cosas:
  * Prender u apagar el ventilador cuando el circuito 1 se lo indique
  * Prender u apagar  el led RGB cuando el circuito 1 se lo indique
  * Prender el color RGB al color indicado por el circuito 1

[Dar clic aqui para ver circuito de manera mas legible el circuito 2](HADWARE/circuitos/circuito_2.png)

<!--style="margin-left:auto;margin-right:auto;width:100%;"-->
<div style="text-align: center;">
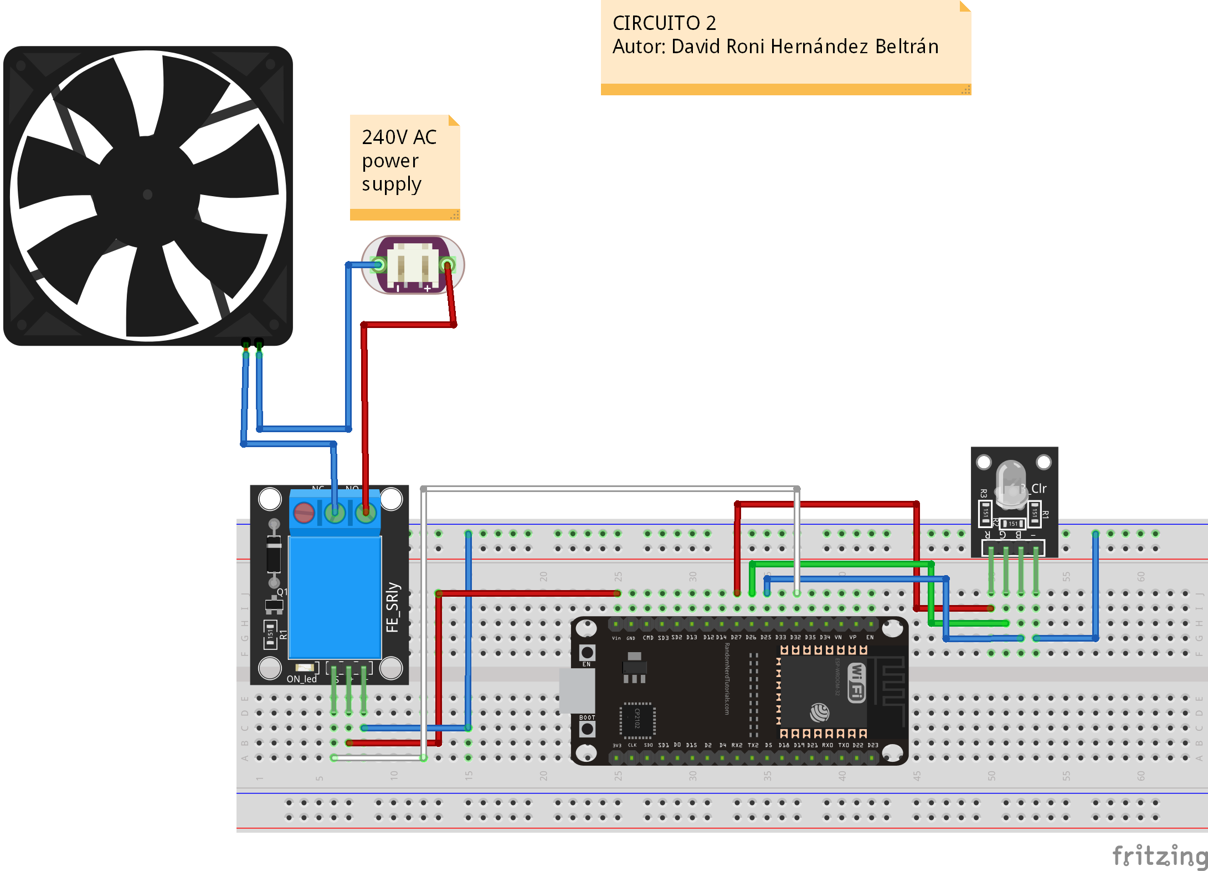
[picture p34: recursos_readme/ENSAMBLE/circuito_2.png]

</div>

<hr>

## **3) Ensamble del proyecto**
<div class="myWrapper" markdown="1" align="center">

[Regresar al menu principal](#menu)
</div>

<hr>

### **3.1) Paso 1**
<div class="myWrapper" markdown="1" align="center">

[Regresar al menu principal](#menu)
</div>

Cumplir con todos los prerrequisitos ya mencionados anteriormente, es decir **conseguir el material e intalar python y los paquetes de python necesarios ya sea en la rasberry pi o en la computadora**

  * [1) Ir al apartado de  prerrequisitos](#1-prerrequisitos)
      * [1.1) Ir al apartado de materiales](#11-materiales)
      * [1.2) Ir al apartado de los paquetes que se deben instalar en python](#12-instalacion-de-paquetes-de-python)

### **3.2) Paso 2**
<div class="myWrapper" markdown="1" align="center">

[Regresar al menu principal](#menu)
</div>

Descargar el codigo fuente de la interfaz grafica que desarrolle  en la rasberry pi o en la computadora, el codigo fuente se encuentra en la direccion: **<< GUI/>>**

[Dar clic aqui para ver el codigo fuente de la interfaz grafica](GUI/)

Para comprobar el correcto funcionamiento del codigo fuente de mi interfaz grafica sin ser necesario las otras conexiones, ejecutar el script <<**mainFast.py**>> ya que dicho script hace funcionar mi interfaz grafica sin ser necesario que este conectado el **<<cirucito 1>>** a los puertos usb de la rasberry pi o la computadora.

Si estas en la rasberry pi, para ejecutar el script no olvidar conceder permisos de ejecución al script, es decir:

<pre>
  <code>
    chmod +x mainFast.py
  </code>
</pre>

Y si quieres concederle todos los permisos, podras hacerlo con:

<pre>
  <code>
    chmod 777 mainFast.py
  </code>
</pre>

Finalmente para ejecutar el script si estas desde la rasberry pi podras hacerlo con:

<pre>
  <code>
    ./mainFast.py
  </code>
</pre>

ya que el archivo el archivo **<<mainFast.py>>** ya incluye en su primer linea: **<<#! /usr/bin/env python3>>**

Tambien podras ejecutar el script con: 

<pre>
  <code>
    python3 mainFast.py
  </code>
</pre>

Una vez ejecutado el script se mostrara mi interfaz grafica, con la cual deberas interactuar para comprobar su correcto funcionamiento, lo que podras hacer sera crear notas u alarmas para serciorar que todo este funcionando correctamente.

### **3.3) Paso 3**
<div class="myWrapper" markdown="1" align="center">

[Regresar al menu principal](#menu)
</div>

Armar el **<<cirucito 2>>**:
[dar clic aqui para ver circuito de manera mas legible el circuito 2](HADWARE/circuitos/circuito_2.png)

Para comprobar  el correcto funcionamiento del **<<cirucito 2>>**  deberas hacer lo siguiente:

* Cargar el script que se encuentra en: <<**HADWARE/script_esp32_test**>>  en el esp32

  [dar clic aqui para ver el script_esp32_test](HADWARE/script_esp32_test)

* Dejar conectado el esp-32 a la computadora

* Descargar la aplicación movil cuyo nombre es: **<< Serial Bluetooth Terminal >>**

  <!--style="margin-left:auto;margin-right:auto;width:100%;"-->
  <div style="text-align: center;">
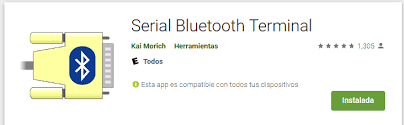
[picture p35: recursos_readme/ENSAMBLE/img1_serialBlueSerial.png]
  
  </div>

* Activar el Bluetooth  en tu dispositivo movil
* Vincularte a traves de Bluetooth con el esp-32, el cual aparece con el nombre de: **<<Cuarto_luzFlamaVentilador>>**

  <!--style="margin-left:auto;margin-right:auto;width:100%;"-->
  <div style="text-align: center;">
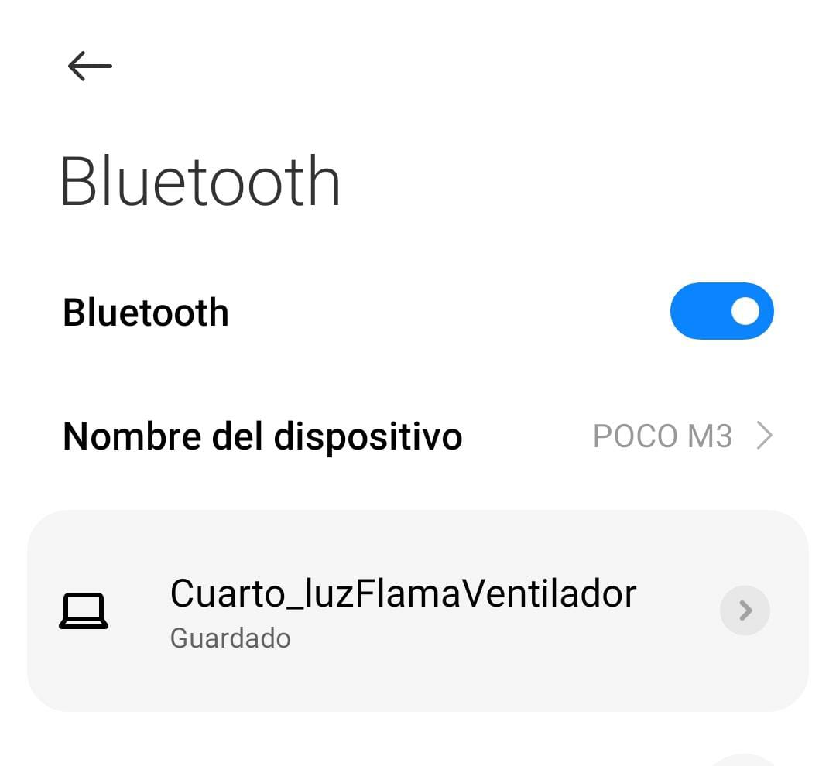
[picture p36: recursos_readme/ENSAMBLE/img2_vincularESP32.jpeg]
  
  </div>

* Abrir la aplicación  **<< Serial Bluetooth Terminal >>** y conectarse con el esp-32, el cual aparece con el nombre de: **<<Cuarto_luzFlamaVentilador>>**, a continuación se muestran los pasos de como hacerlo:

  <!--style="margin-left:auto;margin-right:auto;width:100%;"-->
  <div style="text-align: center;">
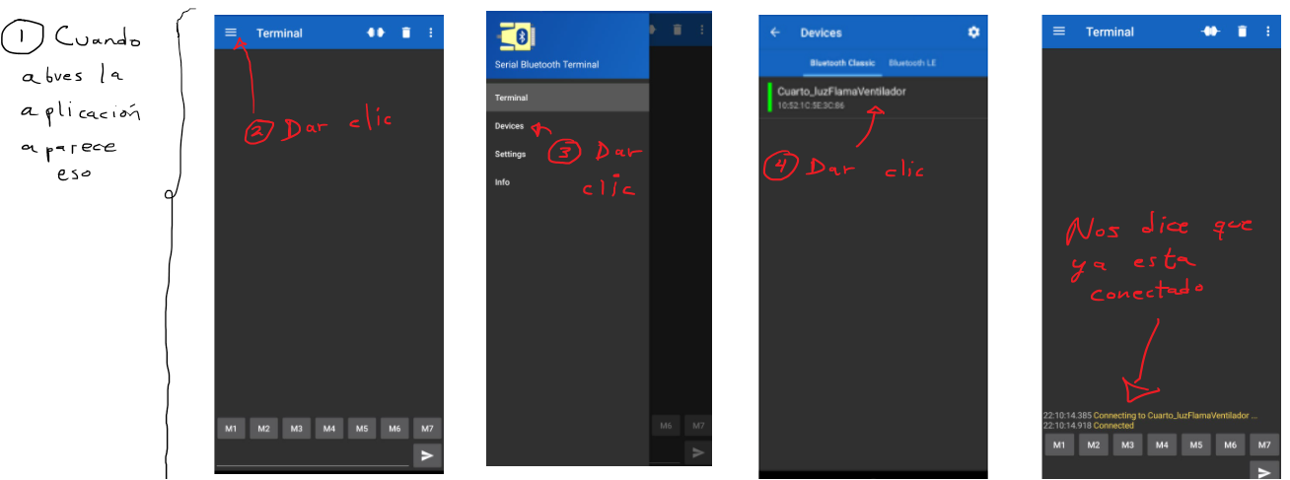
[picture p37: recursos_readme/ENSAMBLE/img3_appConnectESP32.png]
  
  </div>

* Ahora enviar los siguientes mensajes al esp32 atraves de la aplicación **<< Serial Bluetooth Terminal >>** para comprobar el correcto funcionamiento del **<<cirucito 2>>**  : 

  * Si envias: << __10,1  >> deberas recibir un << 5 >> como respuesta del esp-32 y aparte debera prenderse el ventilador

  * Si envias: << __10,1  >> deberas recibir un << 5 >> como respuesta del esp-32 y aparte debera apagarse el ventilador

  * Si envias: << __11,1 __ >> deberas recibir un << 5 >> como respuesta del esp-32 y aparte debera prenderse el led RGB

  * Si envias: << __11,0 __ >> deberas recibir un << 5 >> como respuesta del esp-32 y aparte debera apagarse el led RGB

  * Si el led RGB esta prendido y envias: << __11,2,0 __ >> deberas recibir un << 5 >> como respuesta del esp-32 y aparte debera cambiar a color blanco el led RGB

  * Si el led RGB esta prendido y envias: << __11,2,1 __ >> deberas recibir un << 5 >> como respuesta del esp-32 y aparte debera cambiar a color rojo el led RGB
    
  * Si el led RGB esta prendido y envias: << __11,2,2 __ >> deberas recibir un << 5 >> como respuesta del esp-32 y aparte debera cambiar a color verde el led RGB

  * Si el led RGB esta prendido y envias: << __11,2,3 __ >> deberas recibir un << 5 >> como respuesta del esp-32 y aparte debera cambiar a color azul el led RGB

  * Si el led RGB esta prendido y envias: << __11,2,4 __ >> deberas recibir un << 5 >> como respuesta del esp-32 y aparte debera cambiar a color amarillo el led RGB

  * Si el led RGB esta prendido y envias: << __11,2,5 __ >> deberas recibir un << 5 >> como respuesta del esp-32 y aparte debera cambiar a color magenta el led RGB

  * Si el led RGB esta prendido y envias: << __11,2,6 __ >> deberas recibir un << 5 >> como respuesta del esp-32 y aparte debera cambiar a color cian el led RGB

Una vez comprobado el correcto funcionamiento del **<<cirucito 2>>**, ahora deberas cargar el script que se encuentra en: <<**HADWARE/script_esp32_luzFlamaVentilador**>> en el esp-32

[dar clic aqui para ver el script_arduinoNano_extensionRasberry](HADWARE/script_esp32_luzFlamaVentilador)

### **3.4) Paso 4**
<div class="myWrapper" markdown="1" align="center">

[Regresar al menu principal](#menu)
</div>

Armar el <<**circuito 1**>>, pero aun no conectar los cables USB a los puertos USB de la rasberry pi o computadora 

[dar clic aqui para ver el circuito 1 de manera mas legible](HADWARE/circuitos/circuito_1.png)

Hecho lo anterior ahora deberan cargarse ciertas configuraciones al modulo bluetooth hc-05, para hacer dichas configuraciones, debera conectarse el  cable con salida USB del FTDI a un puerto USB de una computadora que tenga instalado el IDE de arduino, una vez hecho lo anterior se debera abrir el monitor serial del IDE del arduino en el puerto serial que  la computadora le asigno al FTDI, una vez hecho lo anterior recomiendo leer el siguiente manual para saber acerca de las configuraciones al modulo blueetooth hc-05:

[manual de los comandos AT del bluetooth hc-05 ](HADWARE/manuales/configuracionBluetooth_hc05.pdf)

Una vez leido y comprendido el manual, se debera hacer lo siguiente:

* Entrar al modo AT 2
* Con el comando <<**AT+PSWD**>> establecer al  modulo bluetooth hc-05  un codigo de vinculación igual a **<<1234>>** 
* Con el comando <<**AT+ROLE**>> configurar el role del modulo bluetooth hc-05 para que trabaje como <<**esclavo**>>.
* Con el comando <<**AT+NAME**>> establecerle un nombre al modulo bluetooth hc-05 el cual debera ser: <<**blutu_roni**>>

* Aplicar el siguiente comando  <<**AT+UART=9600,0,0**>> para establecer una velocidad y configuración  estandar de comunicación

* Una vez hecho lo anterior debera salirse del modo AT 2 con el comando: <<**AT+RESET**>>

Para comprobar que el modulo bluetooth hc-05 fue configurado existosamente se debera hacer lo siguiente: 
* Activar el bluetooth de tu celular 
* Vincularte con el dispositivo bluetooth cuyo nombre sea: <<**blutu_roni**>>, cuando te pida la contraseña de emparamiento ingresar la contraseña: <<**1234**>> y finalmente una vez emparejado el celular con el modulo bluetooth hc-05, ahora deberas abrir la aplicación que previamente has instalado, es decir la aplicación cuyo nombre es: **<< Serial Bluetooth Terminal >>** y atraves de ella mandarle mensajes al modulo bluetooth hc-05, los cuales deberian verse reflejados en el monitor serial del IDE del arduino, si nos lo vez probablemente sea por que no has cambiado la velocidad del monitor serial a la velocidad 9600 baudios.

Una vez hecho lo anterior seguira otra prueba del correcto funcionamiento del modulo bluetooth hc-05, sin embargo para hacer dicha prueba se debera desemparejar el modulo bluetooth hc-05 del celular, una vez hecho lo anterior se debera hacer lo siguiente:

*  Dejar conectado el cable  USB del FTDI al  puerto USB de la computadora que tiene instalado el IDE de arduino.En el IDE del arduino una vez mas abrir el monitor serial en el puerto que le asigno la computadora al FTDI y configurar la velocidad de comunicación a: 9600 baudios
* Conectar el esp-32 al  puerto USB de la computadora que tiene instalado el IDE de arduino.
* Esperar que el esp-32 se empareje con el  modulo bluetooth hc-05, recordar que esto sera cuando el modulo bluetooth hc-05 haga un doble parpadeo cada 2 segundos aproximadamente.

* En el el monitor serial en el puerto que le asigno la computadora al FTDI y configuraste la velocidad de comunicación a: 9600 baudios empezar a enviar los siguientes mensajes:

  * Si envias: << __10,1  >> deberas recibir un << 5 >> como respuesta del esp-32 y aparte debera prenderse el ventilador

  * Si envias: << __10,1  >> deberas recibir un << 5 >> como respuesta del esp-32 y aparte debera apagarse el ventilador

  * Si envias: << __11,1 __ >> deberas recibir un << 5 >> como respuesta del esp-32 y aparte debera prenderse el led RGB

  * Si envias: << __11,0 __ >> deberas recibir un << 5 >> como respuesta del esp-32 y aparte debera apagarse el led RGB

  * Si el led RGB esta prendido y envias: << __11,2,0 __ >> deberas recibir un << 5 >> como respuesta del esp-32 y aparte debera cambiar a color blanco el led RGB

  * Si el led RGB esta prendido y envias: << __11,2,1 __ >> deberas recibir un << 5 >> como respuesta del esp-32 y aparte debera cambiar a color rojo el led RGB
    
  * Si el led RGB esta prendido y envias: << __11,2,2 __ >> deberas recibir un << 5 >> como respuesta del esp-32 y aparte debera cambiar a color verde el led RGB

  * Si el led RGB esta prendido y envias: << __11,2,3 __ >> deberas recibir un << 5 >> como respuesta del esp-32 y aparte debera cambiar a color azul el led RGB

  * Si el led RGB esta prendido y envias: << __11,2,4 __ >> deberas recibir un << 5 >> como respuesta del esp-32 y aparte debera cambiar a color amarillo el led RGB

  * Si el led RGB esta prendido y envias: << __11,2,5 __ >> deberas recibir un << 5 >> como respuesta del esp-32 y aparte debera cambiar a color magenta el led RGB

  * Si el led RGB esta prendido y envias: << __11,2,6 __ >> deberas recibir un << 5 >> como respuesta del esp-32 y aparte debera cambiar a color cian el led RGB

Si se tiene exito con las pruebas realizadas anteriormente significara que:

* El esp-32 y modulo bluetooth hc-05 funcionan correctamente en conjunto.

Una vez hecho todo lo anterior, ya se podra desconectar el cable  USB del FTDI y tambien ya podra desconectar el esp32 de la computadora.

### **3.5) Paso 5**
<div class="myWrapper" markdown="1" align="center">

[Regresar al menu principal](#menu)
</div>

Una vez armado el <<**circuito 1**>> en el paso anterior, ahora se pedira cargar el script que se encuentra en: <<**HADWARE/script_arduinoNano_extensionRasberry**>> en el arduino nano
[dar clic aqui para ver el script_arduinoNano_extensionRasberry](HADWARE/script_arduinoNano_extensionRasberry)

Ahora se pedira ya conectar los cables USB( cable del FTDI y cable del arduino nano) a  los puertos usb de la rasberry pi o computadora, hecho lo anterior ahora se pedira que se halle que puerto que  le asigno la rasberry pi o computadora a cada dispositivo(FTDI y arduino nano), si estas en la rasberry pi esto se podra hacer haciendo lo siguiente:

Primero habilitar la interfaz en serie del Raspberry Pi:

  <!--style="margin-left:auto;margin-right:auto;width:100%;"-->
  <div style="text-align: center;">
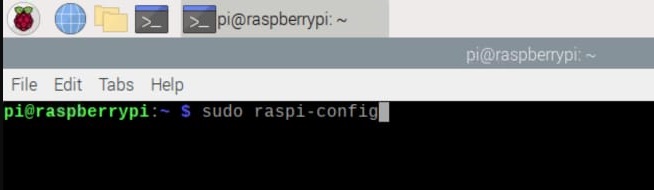
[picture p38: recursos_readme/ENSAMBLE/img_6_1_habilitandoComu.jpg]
  
    
  </div>

  <!--style="margin-left:auto;margin-right:auto;width:100%;"-->
  <div style="text-align: center;">
  
  
  </div>

  <!--style="margin-left:auto;margin-right:auto;width:100%;"-->
  <div style="text-align: center;">
  
  </div>

Segundo: Desconectar los cables USB( cable del FTDI y cable del arduino nano) de  los puertos usb de la rasberry pi y digitar el comando el cual servira para ver las direcciones seriales sin los dos dispositivos conectados.

<pre>
  <code>
    ls /dev/tty*
  </code>
</pre>

Una vez hecho lo anterior ahora conectar el cable USB del arduino nano y volver a digitar el comando anterior para volver a ver las direcciones seriales, sin embargo en esta ocación se vera una mas, la cual correspondera a la direccion serial que le fue asignada al arduino nano.

Una vez hecho lo anterior ahora se debera conectar el cable USB del FTDI y volver a digitar el comando anterior para volver a ver las direcciones seriales, sin embargo en esta ocación se vera otra direccion mas, la cual correspondera al direccion serial que le fue asignada al  del FTDI.

  <!--style="margin-left:auto;margin-right:auto;width:100%;"-->
  <div style="text-align: center;">
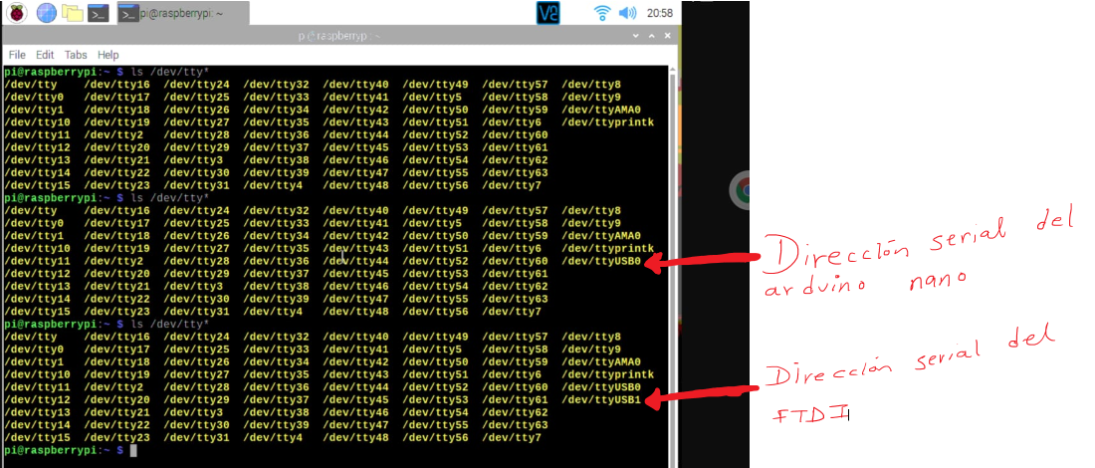
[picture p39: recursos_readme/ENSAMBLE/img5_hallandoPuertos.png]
  
  </div>

Ya sabiendo que direcciones seriales se le asignaron al FTDI y al arduino nano ahora se debera ir al codigo fuente de la interfaz grafica, el cual fue descargado en el PASO 1, y se debera abrir el scipt cuyo nombre es <<**recursos.py**>> para indicarle cuales son los puertos que le asigno la rasberry pi al arduino nano y al FTDI.

 <!--style="margin-left:auto;margin-right:auto;width:100%;"-->
  <div style="text-align: center;">
  
    
  </div>

 <!--style="margin-left:auto;margin-right:auto;width:100%;"-->
  <div style="text-align: center;">
  
  </div>

Y por fin ya podra ser ejecutado el script <<**main.py**>> para que todo el proyecto pueda funcionar, sin embargo no hay que olvidar que....

Si estas en la rasberry pi, para ejecutar el script conceder permisos de ejecución al script, es decir:

<pre>
  <code>
    chmod +x main.py
  </code>
</pre>

Y si quieres concederle todos los permisos, podras hacerlo con:

<pre>
  <code>
    chmod 777 main.py
  </code>
</pre>

Finalmente para ejecutar el script si estas desde la rasberry pi podras hacerlo con:

<pre>
  <code>
    ./main.py
  </code>
</pre>

ya que el archivo el archivo **<<main.py>>** ya incluye en su primer linea: **<<#! /usr/bin/env python3>>**

Tambien podras ejecutar el script con: 

<pre>
  <code>
    python3 main.py
  </code>
</pre>

### **3.6) Paso 6(opccional)**
<div class="myWrapper" markdown="1" align="center">

[Regresar al menu principal](#menu)
</div>

Si estas en la rasberry pi y deseas hacer un archivo **<<.desktop>>** para ejecutar el programa con solo un clic, podras hacerlo haciendo lo siguiente:

* En el codigo fuente que descargaste de la interfaz grafica hay un archivo ubicado en la carpeta <<**GUI/**>> cuyo nombre es <<**desktop.desktop**>>, dicho archivo deberas copiarlo en el lugar donde quieras, para que al dar un clic sobre dicho archivo se ejecute el programa.

* Una vez copiado dicho archivo en el lugar que quieras, ahora deberas abrirlo y modificarlo.Al abrirlo veras algo similar a lo siguiente:

 <!--style="margin-left:auto;margin-right:auto;width:100%;"-->
  <div style="text-align: center;">
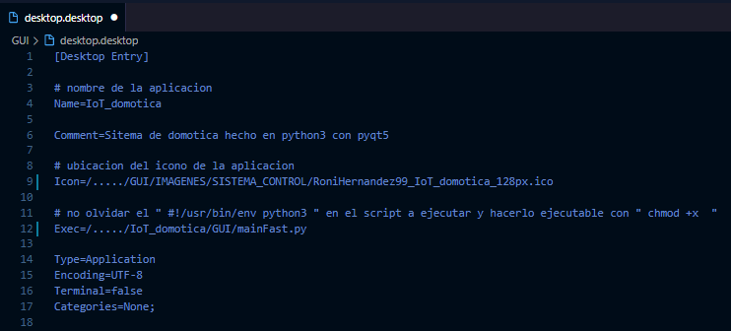
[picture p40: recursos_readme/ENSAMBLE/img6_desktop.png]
  
  </div>

Lo que deberas hacer es modificar las siguientes lineas de dicho archivo:

<pre>
  <code>
  Icon=/...../GUI/IMAGENES/SISTEMA_CONTROL/RoniHernandez99_IoT_domotica_128px.ico
  Exec=/...../IoT_domotica/GUI/mainFast.py
  </code>
</pre>

Deberas remaplazar los puntos suspensivos de las dos lineas, por la dirección absoluta en la que se encuentra la carpeta <<**GUI/**>> que es la que almacena el codigo fuente de la interfaz grafica.

Ejemplo: Supogamos que la carpeta  <<**GUI/**>> que es la que almacena el codigo fuente de la interfaz grafica, se encuentra almacenada en mi rasberry pi en la dirección: <<**home/pi/Desktop/proyectos/IoT_domotica**>>, entonces en la dos lineas anteriores debere ramplzar los puntos suspensivo por dicha direccion es decir debera hacer lo siguiente:

<pre>
  <code>
  Icon=/home/pi/Desktop/proyectos/IoT_domotica/GUI/IMAGENES/SISTEMA_CONTROL/RoniHernandez99_IoT_domotica_128px.ico
  Exec=/home/pi/Desktop/proyectos/IoT_domotica/IoT_domotica/GUI/main.py
  </code>
</pre>

Una vez hecho lo anterior se le deberan dar permisos a este archivo que modificaste, es decir al archivo <<**desktop.desktop**>>

<pre>
  <code>
    chmod 777 desktop.desktop
  </code>
</pre>

Y con eso todo al dar clic sobre dicho archivo deberia abrir el programa.

 <!--style="margin-left:auto;margin-right:auto;width:100%;"-->
  <div style="text-align: center;">
  
  </div>

<hr>

### **4) Posibles errores**
<div class="myWrapper" markdown="1" align="center">

[Regresar al menu principal](#menu)
</div>

<hr>

## Driver del arduino nano:

* ¿El ID de Arduino no reconoce al arduino nano? 

  * Solucion: Instalar los drivers respectivos del arduino nano:

  * En el siguiente video explican como instalar los drivers respectivos y donde encontrarlos: https://www.youtube.com/watch?v=1-ZyM0dGCY8

  * En el siguiente link estan los drivers del arduino nano: http://www.wch-ic.com/downloads/CH341SER_EXE.html 

* ¿Problemas con el audio con la rasberry pi 4B con el sistema operativo Rasbian?

  * Asegurate de que estes conectado el HDM0 de las rasberri
  * Asegurate de que al dar clic derecho sobre el icono de bocina que se encuentra en la parte superior de la pantalla este seleccionada la opccion: HDMI y NO la opcción AV Jack

<hr>

### **5) Fuentes de informacion:**
<div class="myWrapper" markdown="1" align="center">

[Regresar al menu principal](#menu)
</div>

<hr>

* El pdf que adjunte en el apartado <<**HADWARE/manuales/desktopLinux.pdf**>> fue un pdf que se obtuve de la siguiente pagina de internet: https://www.hackster.io/kamal-khan/desktop-shortcut-for-python-script-on-raspberry-pi-fd1c63 la razon por la cual la converti a pdf, es para tener un respaldo de esa valiosa información.

  [dar clic aqui para ver el pdf](HADWARE/manuales/desktopLinux.pdf)

* El pdf que adjunte en el apartado <<**HADWARE/manuales/alimentacionEsp32.pdf**>> fue un pdf que se obtuve de la siguiente pagina de internet: https://emariete.com/alimentar-desde-nodemcu-wemos-mini-d1-y-arduino/ la razon por la cual la converti a pdf, es para tener un respaldo de esa valiosa información.

  [dar clic aqui para ver el pdf](HADWARE/manuales/alimentacionEsp32.pdf)

* El pdf que adjunte en el apartado <<**HADWARE/manuales/configuracionBluetooth_hc05.pdf**>> fue un pdf que se obtuve de la siguiente pagina de internet: https://naylampmechatronics.com/blog/24_configuracion-del-modulo-bluetooth-hc-05-usando-comandos-at.html la razon por la cual la converti a pdf, es para tener un respaldo de esa valiosa información.

  [dar clic aqui para ver el pdf](HADWARE/manuales/configuracionBluetooth_hc05.pdf)

* El pdf que adjunte en el apartado <<**HADWARE/manuales/comunicacionSerialArduinoRasberryPi.pdf**>> fue un pdf que se obtuve de la siguiente pagina de internet: https://www.aranacorp.com/es/comunicacion-en-serie-entre-raspberry-pi-y-arduino/   
la razon por la cual la converti a pdf, es para tener un respaldo de esa valiosa información.

  [dar clic aqui para ver el pdf](HADWARE/manuales/comunicacionSerialArduinoRasberryPi.pdf)

* El pdf que adjunte en el apartado <<**HADWARE/manuales/comunicacionSerialArduinoRasberryPi_2.pdf**>> fue un pdf que se obtuve de la siguiente pagina de internet: https://diyi0t.com/arduino-to-raspberry-pi-serial-communication/  
la razon por la cual la converti a pdf, es para tener un respaldo de esa valiosa información.

  [dar clic aqui para ver el pdf](HADWARE/manuales/comunicacionSerialArduinoRasberryPi_2.pdf)

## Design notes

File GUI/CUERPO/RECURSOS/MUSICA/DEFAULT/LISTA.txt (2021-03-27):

1) Beach_MBB
https://www.youtube.com/watch?v=CPy2TLPbpVY&list=PLzCxunOM5WFLNCSF0UEHZqFJJlmdeL71S&index=35

2)Happy_MBB 
https://www.youtube.com/watch?v=g6swHZbWtRc&list=PLzCxunOM5WFLNCSF0UEHZqFJJlmdeL71S&index=18

3)Journey_Declan
https://www.youtube.com/watch?v=zDVKg3riNGU&list=PLzCxunOM5WFLNCSF0UEHZqFJJlmdeL71S&index=46

4)Moldy_Lotion
https://www.youtube.com/watch?v=GSSdXximD7c&list=PLzCxunOM5WFLNCSF0UEHZqFJJlmdeL71S&index=56

5)Spring_Ikson
https://www.youtube.com/watch?v=5WPnrvEMIdo&list=PLzCxunOM5WFLNCSF0UEHZqFJJlmdeL71S&index=36

6)We Are One
https://www.youtube.com/watch?v=Ssvu2yncgWU&list=PLzCxunOM5WFLNCSF0UEHZqFJJlmdeL71S&index=2

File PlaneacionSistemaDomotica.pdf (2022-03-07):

### SISTEMA DE DOMÓTICA DE RONI HERNÁNDEZ

Mi proyecto consistirá en un pequeño sistema de domótica el cual estará administrado por una interfaz gráfica de escritorio que estará

ejecutando una Rasberry pi, este sistema de domótica deberá ser capaz de hacer lo siguiente:

- Controlar el prendido y el apagado de un foco RGB, asi como el color al que este prende entre una variedad de 7 posibles colores (blanco, verde, amarillo, rojo, magenta, azul, cian), controlar el prendido y el apagado de un ventilador, avisar al usuario cuando se detecte un incendio, permitir la programación de alarmas y ofrecer un sistema de administración de deberes.

### 1. EXPLICACIÓN DEL SOFWARE DEL PROYECTO

A continuación, se adjuntará una imagen de cómo se deberá ver el sistema de domótica y una breve explicación de cada apartado de ella:

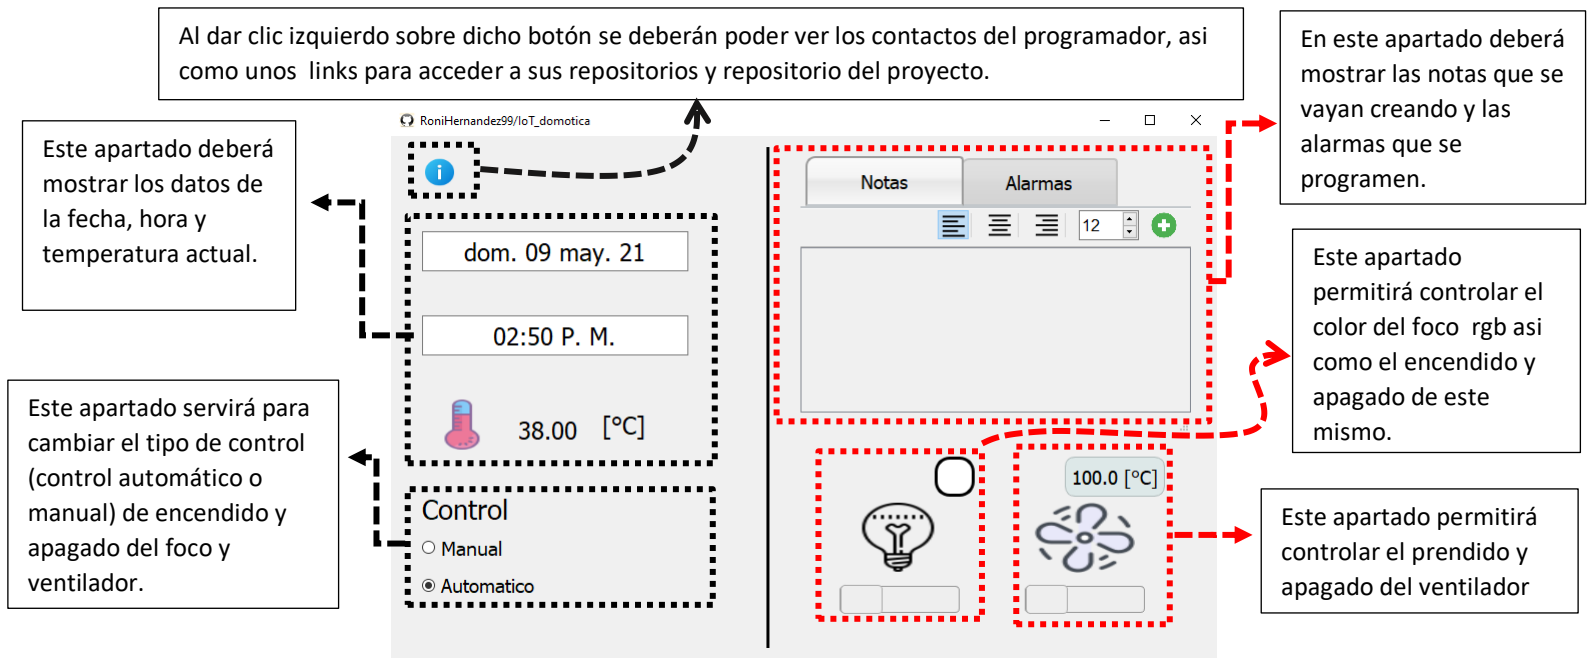
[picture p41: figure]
En este apartado deberá mostrar las notas que se vayan creando y las alarmas que se programen.; Este apartado permitirá controlar el color del foco rgb asi como el encendido y apagado de este mismo.; Este apartado permitirá controlar el prendido y apagado del ventilador; Este apartado servirá para cambiar el tipo de control (control automático o manual) de encendido y apagado del foco y ventilador.; Este apartado deberá mostrar los datos de la fecha, hora y temperatura actual.

Explicado lo anterior ahora proseguiré a explicar de una forma más detallada cada función de lo que deberá hacer el sistema de domótica:

### 1. PRENDIDO MANUAL Y AUTOMÁTICO DE LOS OBJETOS: LEDRGB Y VENTILADOR

El usuario deberá escoger con que modalidad desea administrar el prendido u apagado de los objetos (ventilador y led RGB), eso significa que ambas modalidades no podrán funcionar al mismo tiempo, es decir:

- Si se elige controlar el prendido y apagado de los objetos de forma automática no se podrán controlar de forma manual, por el contrario, si se elige controlar el prendido y apagado de forma manual no se podrán controlar de forma automática

Es importante mencionar que la GUI deberá ofrecer una manera sencilla de cambiar de control automático a control manual y viceversa

Modalidad de prendido de los objetos | Imágenes
Manual-. En esta modalidad la GUI deberá desbloquear a las barras deslizadoras para que el usuario pueda manipularlas con el fin de prender o apagar el objeto que quiera.

Automática-. En esta modalidad la GUI deberá bloquear a las barras deslizadoras para que el usuario no pueda manipularlas, ya que los objetos solo podrán ser prendidos de forma automática.

¿Cómo funciona exactamente cada modalidad?

Dispositivo | Tipo de encendido y apagado
| AUTOMATICO | MANUAL | ILUSTRACIÓNES DE MANIPULACION MANUAL
LED RGB | Si se detecta un aplauso o un sonido similar, entonces se deberá prender el LED RGB si se encontraba apagado, o se deberá apagar si se encontraba prendido. | Atreves de una barra deslizante que se encontrará inmersa en la GUI, el usuario podrá apagar o prender el objeto (led RGB o ventilador): Si desliza la barra a la izquierda se deberá apagar al objeto. Si desliza la barra a la derecha se deberá prender al objeto.
VENTILADOR | Si se detecta una temperatura mayor o igual a la que el usuario estableció se deberá prender el ventilador, en caso contrario se apagará. Mas adelante se explicará cómo se deberá modificar la temperatura a la cual prenda el ventilador

Foco apagado de
forma manual

Foco prendido de
forma manual
Ventilador apagado de forma manual | Ventilador prendido de forma manual

Al dar clic izquierdo sobre dicho botón se deberán poder ver los contactos del programador, asi como unos links para acceder a sus repositorios y repositorio del proyecto.

### 2. CAMBIANDO EL COLOR DEL LED

El sistema deberá permitir al usuario poder cambiar el color con el que prende el led RGB entre una variedad de 7 posibles colores (blanco, verde, amarillo, rojo, magenta, azul, cian) a partir de los siguientes pasos:

Pasos para cambiar el color del foco RGB

### 1. Dar clic izquierdo

sobre el botón con
forma de cuadro con
esquinas curveadas

### 2. Al hacer lo anterior se deberá

desplegar una barra con los colores a los que el led RGB deberá poder cambiar, se deberá dar clic izquierdo sobre el color que se desee.

### 3. Al dar clic sobre el color deseado, el menú de colores se cerrará, y se

deberá poder ver que el botón con forma de cuadro con esquinas curveadas cambio al color que se escogió, esto significara que el cambio de color se efectuó con éxito.

Observaciones:
- Si se cambia el color del led RGB mientras este se encuentra apagado, no se deberá visualizar el cambio de color hasta que el led RGB se prenda, es decir si se efectuará el cambio de color del led RGB pero como se encuentra apagado, no se podrá apreciar dicho cambio.
- Si se cambia el color del led RGB mientras este esté prendido, se deberá poder apreciar el cambio de color casi de una manera instantánea.
3. ESTABLECIENDO LA TEMPERATURA A LA CUAL PRENDERA EL VENTILADOR.

Si se escoge prender o apagar el ventilador de forma automática la GUI del sistema de domótica le deberá permitir al usuario establecer la temperatura a la cual desea que se prenda el ventilador, para escoger dicha temperatura el usuario deberá hacer lo siguiente:

### 3. MOSTRANDO LA HORA, EL DÍA Y LA TEMPERATURA

El sistema deberá mostrar al usuario:

- La fecha en la cual se encuentra (nombre del día, numero de día, nombre del mes, año)
- La hora en la cual se encuentra (hora, minuto, AM/PM )
- La temperatura actual a la que se encuentra. Es importante mencionar que cada vez que el sistema detecte una variación de temperatura de +- 0.3 [°C] se deberá mostrar dicho cambio en la GUI

A continuación, se adjuntará la imagen de cómo se deberán mostrar los datos descritos anteriormente:

Pasos para establecer la temperatura a la cual se prendera el ventilador de forma automática

### 1. Dar clic izquierdo

sobre el botón con
forma de rectángulo con
esquinas curveadas.

### 2. Se desplegará una ventana emergente en donde se

deberá ingresar la temperatura a la cual se desea que se prenda el ventilador, una vez escrita dicha temperatura se deberá dar clic izquierdo sobre el botón guardar.

### 3. Una vez realizado el paso número 2 se deberá ver

que la ventana se cerrera, y el botón con forma de rectángulo con esquinas curveadas cambiara a la temperatura que se escogió.

Para este ejemplo:
- Si el sistema está en modo automático y detectara que la temperatura es mayor o igual a 25[°C] y el ventilador se encuentra apagado entonces: el sistema deberá prender el ventilador.
- Si el sistema está en modo automático y detectara que la temperatura es menor a 25 [°C] y el ventilador se encuentra prendido entonces: el sistema deberá apagar el ventilador.

### 4. SISTEMA DE NOTAS

La GUI deberá permitir al usuario agregar deberes con la finalidad de que cada que vez que termine un deber, el usuario pueda eliminarlo de la lista de deberes y sentir esa satisfacción personal de cumplir sus deberes, a continuación, se adjuntan los pasos que se deberán seguir para agregar y eliminar deberes:

Como deberán ser agregadas y eliminadas las notas

### 1. Dar clic izquierdo sobre el botón con

forma de rectángulo que dice: ‘Notas’

### 2. Para agregar un deber se deberá

dar clic izquierdo sobre el botón redondo de color verde con una cruz blanca dentro.

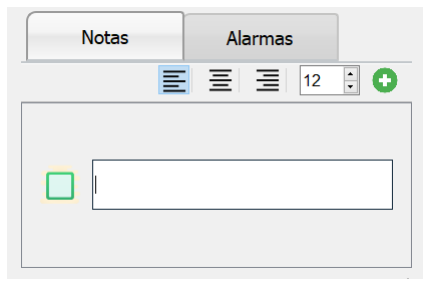
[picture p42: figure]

### 3. Una vez realizado el paso número 2, la GUI deberá

desplegar un rectángulo blanco cuya finalidad será que dentro de él se escriba el deber a realizar.

### 4. Para este ejemplo se escribirá el

deber ‘Hacer tarea’.

### 5. Si se desea agregar más deberes

se deberán repetir los pasos 1,2 y 3, para este ejemplo se agregarán 2 deberes más: ‘Hacer ejercicio’, ‘Estudiar música’

### 6. Una vez hecho un deber se deberá dar clic izquierdo

sobre el cuadrado que se encuentra al lado izquierdo del deber que se realizó.
Para este ejemplo: se simulará que ya se realizó el deber: ‘Hacer tarea’ por tal motivo se debe dar clic izquierdo sobre el cuadro que se encuentra al lado izquierdo del deber: ‘Hacer tarea’

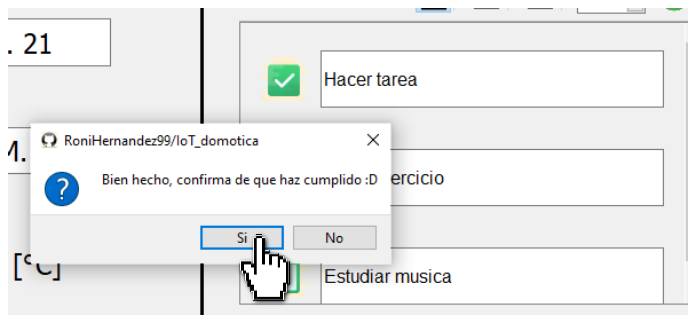
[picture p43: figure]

### 7. Al hacer el paso número 6 se deberá desplegar el siguiente cuadro de

dialogo, el cual preguntara si efectivamente se realizó dicho deber, el usuario deberá dar clic sobre la opción ‘si’ para confirmar que efectivamente ya realizo dicho deber

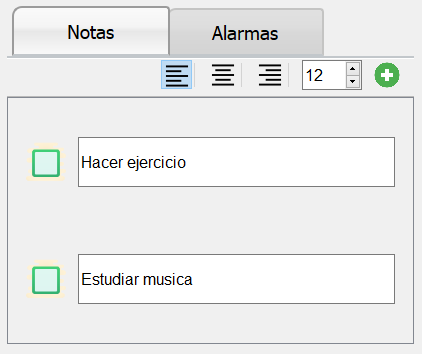
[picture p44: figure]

### 8. Al hacer le paso anterior se deberá poder que el deber

realizado (para este ejemplo el deber: ‘Hacer tareas’) ya no se encuentra en la lista de notas porque ya se le dijo al programa que dicho deber ha sido realizado.

Es importante mencionar que el sistema de domótica debe permitir modificar tanto el tamaño y posición de los deberes, a continuación, se mostrará como deberá poder hacerse eso:

Pasos para editar el tamaño y la posición de las notas

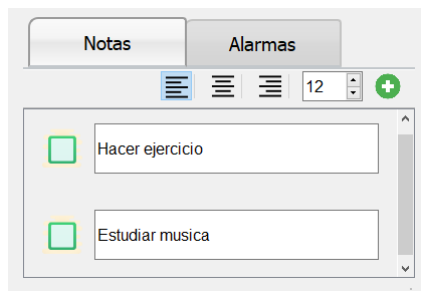
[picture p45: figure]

### 1. Para este ejemplo se parte de que se

tienen las notas: ‘Hacer ejercicio’ y ‘Estudiar música’

2. Si se deseara cambiar el tamaño de la letra de los deberes se deberá modificar el valor numérico del rectángulo que se encuentra a lado izquierdo del botón verde, para este ejemplo se cambiara a un tamaño de letra igual a 20.
3. Si se desea alinear los deberes se deberá dar clic sobre el icono respectivo de alineación, para este ejemplo se alinearán los deberes al centro, por tal motivo se da clic izquierdo sobre dicho icono.

### 5. SISTEMA DE ALARMAS

El sistema de alarmas deberá permitir al usuario agendar sus alarmas tal y como lo hace un teléfono celular, es decir permitirá al usuario:

- Asignar un nombre a la alarma
- Escoger la canción que tocará la alarma al ejecutarse entre una lista de canciones que ofrecerá la GUI de forma default o canciones que el usuario puede importar desde su administrador de archivos.
- Escoger la hora y el día o los días en las cuales la alarma debe sonar
- Crear como máximo un numero de 50 alarmas
- Editar alarmas que ya fueron creadas.
- Eliminar alarmas que ya fueron creadas.
- Desactivar o activar una o varias alarmas.

A continuación, se proseguirá a explicar cómo se deberá poder crear una alarma:

Pasos crear alarmas

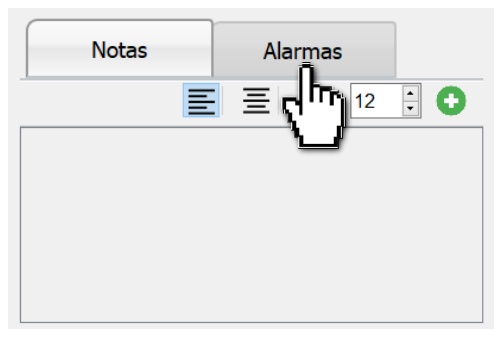
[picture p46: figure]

### 1. Dar clic izquierdo sobre el botón

con forma de rectángulo que dice: ‘Alarmas’

### 2. Para poder agregar una alarma se

deberá dar clic izquierdo sobre el botón redondo de color verde con una cruz blanca dentro

### 3. Al realizar el paso 2, se aparecerá un cuadro de dialogo

el cual servirá para ingresar los datos de la alarma que se desea crear. A continuación, se proseguirá a explicar cada apartado del cuadro de dialogo.

5.1 EXPLICACIÓN DEL CUADRO DE LA VENTANA QUE SE ABRIRÁ CUANDO SE DESEE CREAR O EDITAR UNA ALARMA:

### 5.1.1 Explicación más detallada sobre como elegir un sonido de alarma

Pasos para establecer un sonido de alarma de la lista de reproducción de ‘Pistas default’

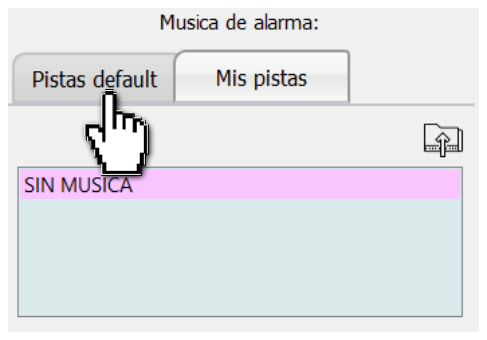
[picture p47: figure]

### 1. Primero deberá escogerse la lista

de reproducción ‘Pistas default’ dando clic izquierdo sobre el botón respectivo.

### 2. Se deberán apreciar los nombres de

la canción que vienen de forma default en la GUI, para escoger una canción se deberá dar clic sobre el nombre de la canción deseada

### 3. Para este ejemplo se escogerá la canción cuyo

nombre es ‘4_moldy_lotion. mp3’ por ello se deberá dar clic izquierdo sobre dicho nombre, una vez hecho eso se verá seleccionado con un color rosa el nombre lo cual significara que se ha escogido con éxito y aparte empezara a sonar dicha canción.

Para indicar que días debe sonar la alarma se deberá dar clic izquierdo sobre el cuadro que se encuentra debajo del nombre del día.

Para escoger el sonido que ejecutara la alarma al ser hora de activarse, habrá dos listas de reproducción cuyos nombres son: ‘Pistas default’ y ‘Mis pistas’ estas esta deberán mostrar los nombres de los sonidos que pueden ser elegidos, para escoger una lista de reproducción deberá ser suficiente el solo dar un clic izquierdo sobre su nombre y para escoger un sonido contenido en la lista de reproducción deberá bastar con dar clic izquierdo sobre el nombre del sonido

En este apartado deberá escribirse la hora a la cual sonara la alarma, la restricción de esto es que solo se podrá elegir la hora y el minuto en que sonara la alarma, es decir la máxima precisión de la alarma serán los minutos.

Este apartado deberá servir para escoger el asunto de la alarma, es importante mencionar que una alarma podrá tener un solo asunto, de los cuatro siguientes: ‘Despertar’,‘Domir’ ,‘Deberes’,‘Otro’ la importancia de elegir un asunto es que cuando suene la alarma, aparte de reproducir la canción que se eligió tambien sonara un pequeño mensaje en función del asunto escogido para simular un asistente

En este apartado deberá ingresarse el nombre de la alarma que se está creando, la restricción de esto que el nombre solo puede tener como máximo 15 caracteres, y únicamente los caracteres válidos serán letras minúsculas mayúsculas y números

Para terminar de crear o editar una alarma deberá darse clic sobre este botón

Pasos para establecer un sonido de alarma de la lista de reproducción de ‘Mis pistas’

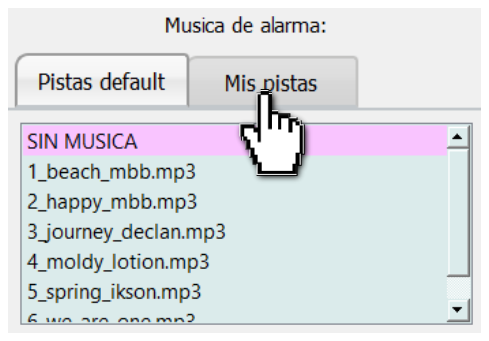
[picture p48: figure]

### 1. Primero deberá escogerse la lista de

reproducción ‘Mis pistas’ dando clic izquierdo sobre el botón respectivo.

### 2. Si no se ha agregado ninguna canción

deberá aparecer la lista de reproducción vacía, tal y como se ve en la imagen

### 3. Para agregar una canción se deberá dar clic

sobre el botón de forma de carpeta el cual al hacer clic sobre la GUI deberá abrir el explorador de archivos el cual permitirá elegir la canción que se desea agregar desde donde la ubicación de donde se encuentre.

### 4. A través el explorador de archivos se

deberá escoger la canción que se desea subir

### 5. Para este ejemplo la canción que se

escogió fue ‘emotional-inspiring…’

### 6. Una vez escogida la canción deberá aparecer

en la lista de reproducción lista para ser seleccionada

### 4. Como la canción que se escogió ya

aparece en la lista de reproducción, ya podrá ser escogida dando clic izquierdo sobre el nombre de esta.

Si se desea importar una canción cuyo nombre es igual a una de las cuales ya fueron importadas no cargara la canción.

No se permite importar canciones con una duración mayor a 6 minutos.
Los únicos formatos de canciones a importar son ‘.mp3’ y ‘.wav’

Eliminar una canción que se importo

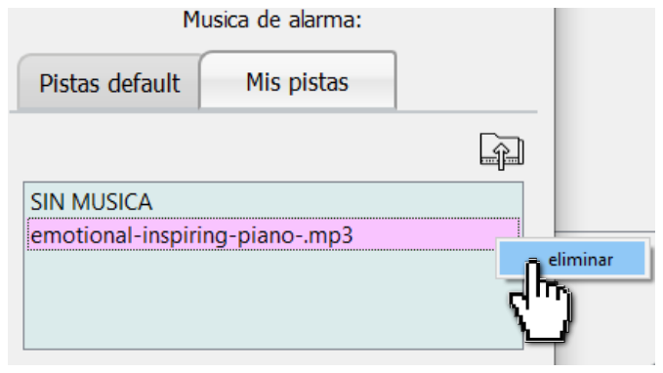
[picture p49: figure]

1. Primero deberá darse clic izquierdo sobre el nombre de la canción que se desea eliminar y posteriormente clic derecho una vez que este marcado de color rosa | 2. Al hacer el paso 1 se aparecerá la opción de eliminarla, se debe dar clic izquierdo sobre dicha opción | 3. Aparecerá un cuadro para confirmar la eliminación, se deberá dar clic izquierdo sobre la opción ‘Si’
| Puntos para considerar: Si se elimina una canción que era la canción de una u otras alarmas, se preguntara antes de ser eliminada, y si se confirma la eliminación las alarmas que tenían esa canción como sonido de alarma ahora no deberán tener sonido de alarma hasta que se les asigne uno nuevamente, en la imagen de derecha se mostrara un ejemplo de que deberá pasar si se desea eliminar una canción que ya fue escogida como sonido de alarma de otras alarmas

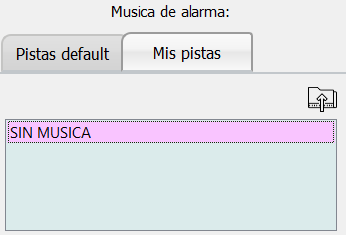
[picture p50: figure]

4.Finalmente dicha canción ya no deberá aparecer en la lista de reproducción, lo cual significara que fue exitosamente eliminada | Se puede apreciar como el cuadro de dialogo explica que es lo que pasaría si se eliminara una canción que ya fue definida como sonido de alarma de otras alarmas.

5.2 UNA VEZ YA EXPLICADA LA VENTANA QUE SE ABRE CUANDO SE DESEA CREAR UNA ALARMA SE PROSEGUIRÁ A DAR UN EJEMPLO DE CÓMO SE DEBERÁ PODER CREAR UNA ALARMA PASO A PASO.

Pasos para crear una alarma que se llame: horaEscuela la cual sonara los días: lunes,martes,miércoles,jueves y viernes a las 4:45 am la cual servirá para despertar y la canción que ejecutara será una de las que vienen integradas por default:

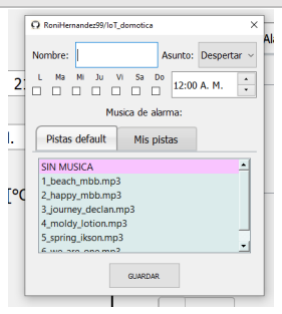
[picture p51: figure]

1. Damos clic izquierdo | 2. Damos clic izquierdo | 3. Se desplegara una ventana, la cual deberá ser llenada con los datos respectivos de la alarma que se desea crear.

5.2.1 Asignándole un nombre a la alarma asi como el asunto, los días que deberá sonar y la hora a la que sonará:

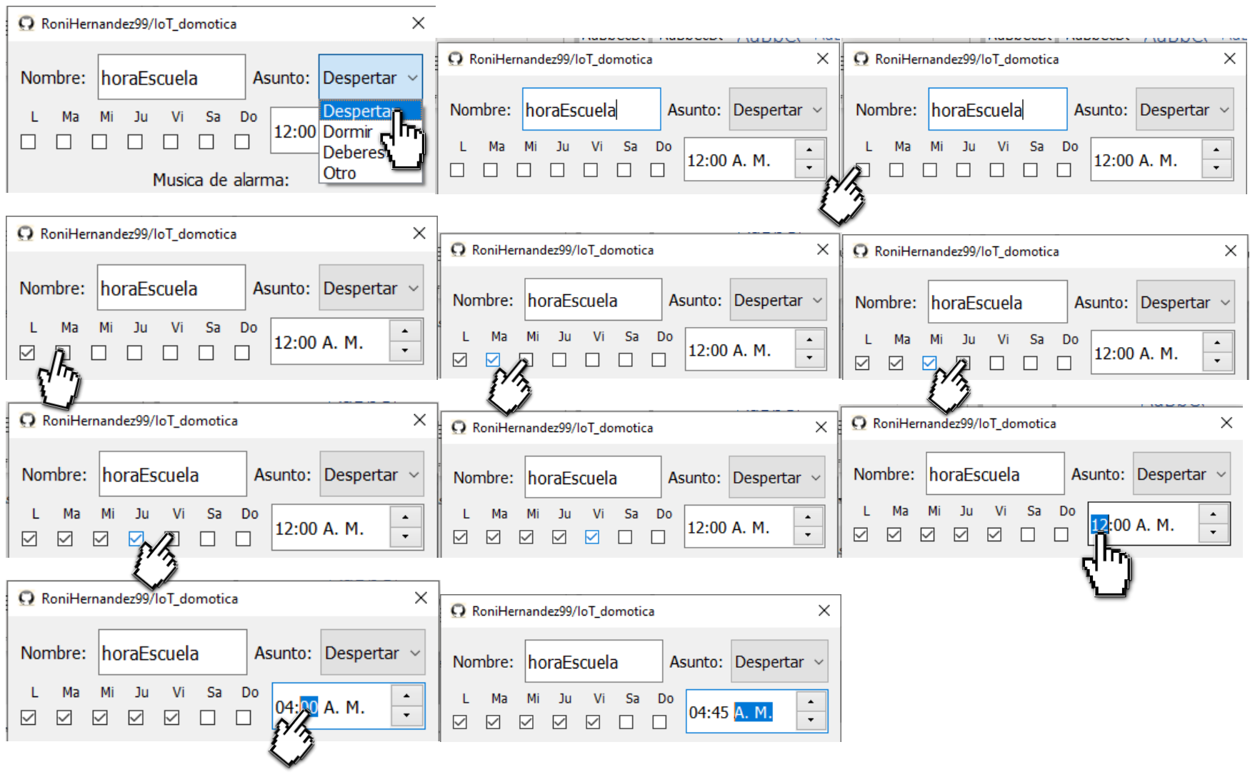
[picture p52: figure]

### 5.2.2 Escogiendo la canción que se tocara cuando la alarma se active:

5.2.3 Finalmente, ya que se hizo todo lo anterior lo único que faltara es dar clic izquierdo sobre el botón cuyo nombre es ‘GUARDAR’

Una vez hecho lo anterior se podrá observar que la alarma fue creada con éxito si aparece en la siguiente parte de la GUI como la siguiente imagen

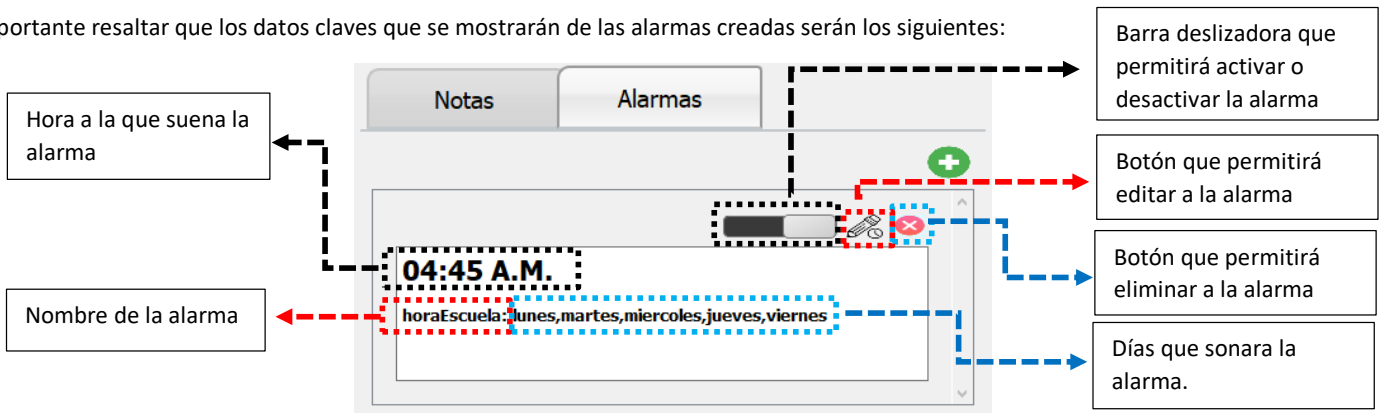
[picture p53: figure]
Hora a la que suena la alarma; Nombre de la alarma; Días que sonara la alarma.; Botón que permitirá eliminar a la alarma; Botón que permitirá editar a la alarma; Barra deslizadora que permitirá activar o desactivar la alarma

Es importante resaltar que los datos claves que se mostrarán de las alarmas creadas serán los siguientes:

5.3 ¿QUÉ PASA SI SE CREA OTRA ALARMA?

Si se crea más de una alarma y ya no alcanza el espacio para ser mostradas todas las alarmas, se deberá aparecer una barra lateral a la derecha que permita visualizar todas las alarmas creadas y asi el espacio no sea un problema, por ejemplo:

5.4 ¿CÓMO SE DEBERÁ PODER EDITAR UNA ALARMA?

Si se deseara editar una alarma, se debera dar clic izquierdo sobre el icono del lápiz que se encuentra en su esquina superior derecha, por ejemplo: si se desea editar la alarma ‘empezarCocinar’ se deberá hacer lo siguiente:

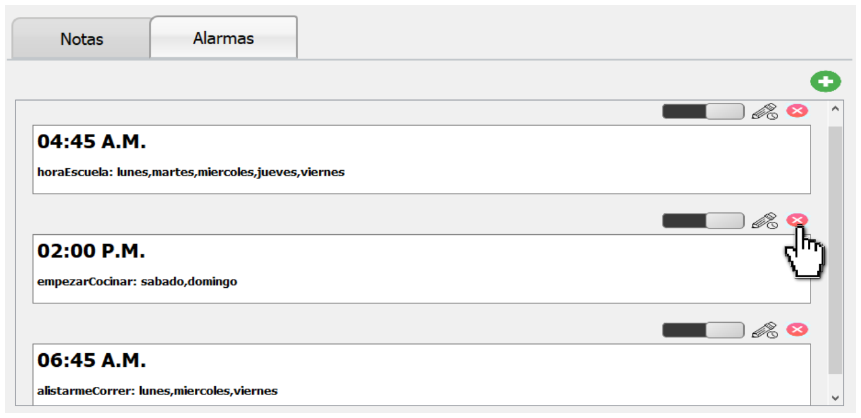
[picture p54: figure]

### 1. Dar clic sobre el lápiz que se encuentra en la esquina superior derecha de

la alarma que queremos editar

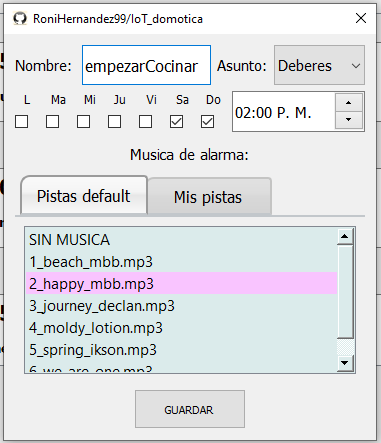
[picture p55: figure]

### 2. Despues de hacer el paso uno, automáticamente se

deberá desplegar la ventana que permite crear alarmas, pero ahora con los valores de la alarma que se desea editar

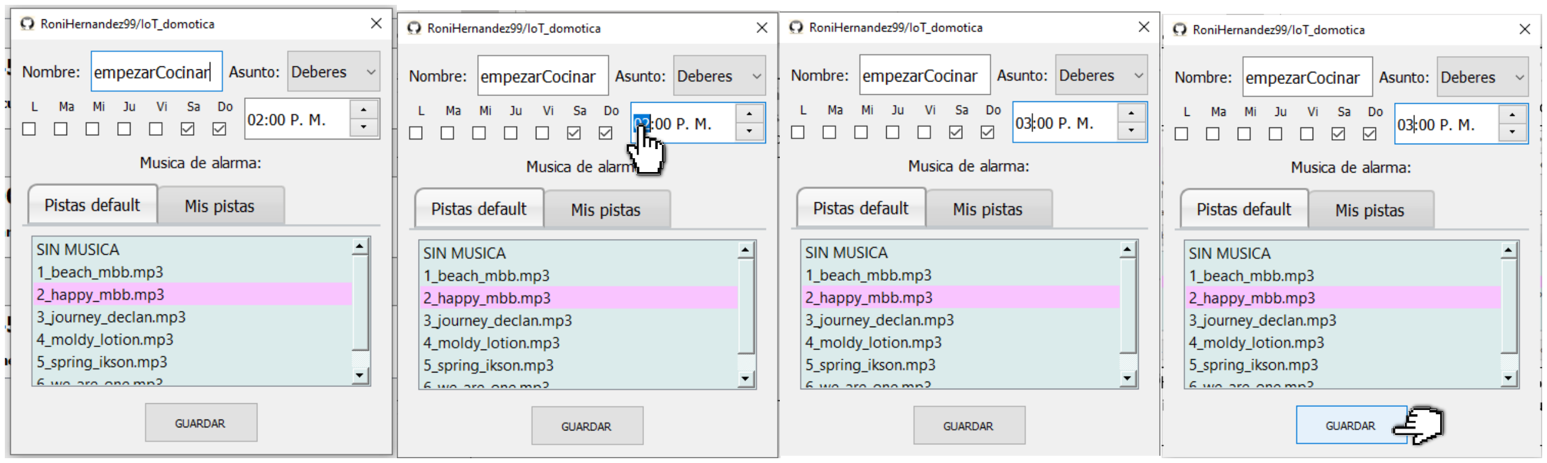
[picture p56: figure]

3. Si se desea editar algo se deberá poder hacerlo libremente y en caso de hacerlo para que se guarden los nuevos cambios deberá darse clic en guardar cambios ya que de lo contrario no se guardarían los cambios realizados para este ejemplo solo se cambió la hora a la que suena, de: 2:00 pm por la hora de 3:00 pm

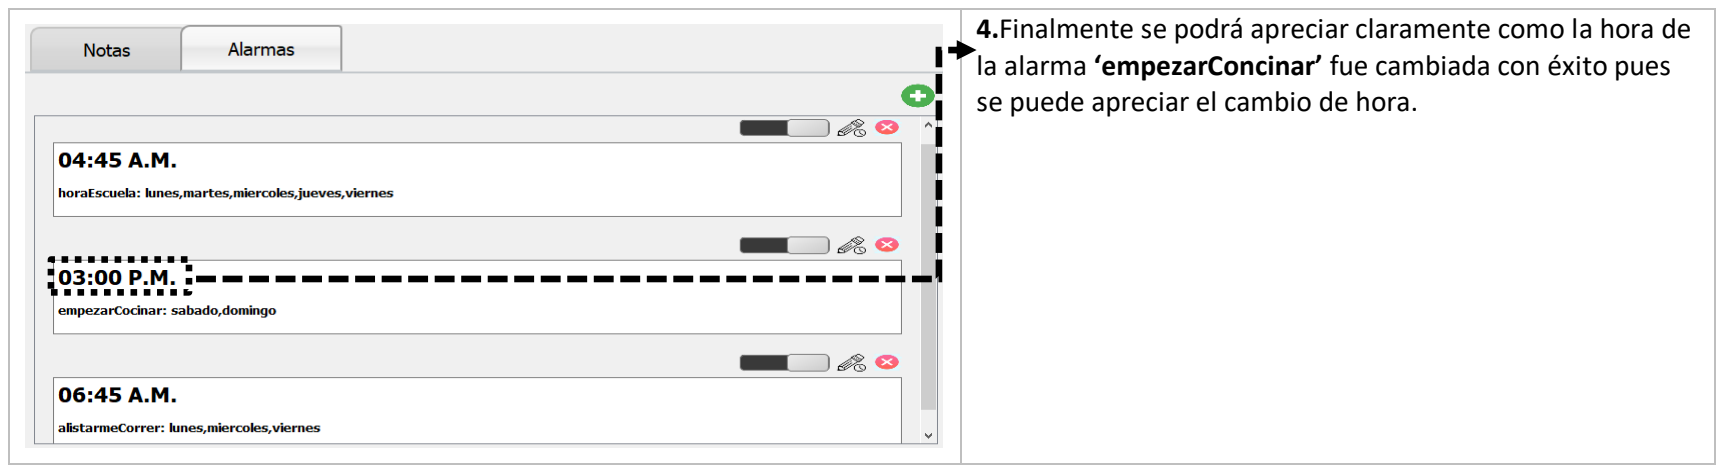
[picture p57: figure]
se puede apreciar el cambio de hora.

4.Finalmente se podrá apreciar claramente como la hora de la alarma ‘empezarConcinar’ fue cambiada con éxito pues

5.4 ¿CÓMO SE DEBERÁ ELIMINAR UNA ALARMA?

Si se deseara eliminar una alarma, se deberá dar clic izquierdo sobre el icono del tache que se encuentra en su esquina superior derecha, por ejemplo: si se deseara eliminar la alarma ‘empezarCocinar’ se deberá hacer lo siguiente:

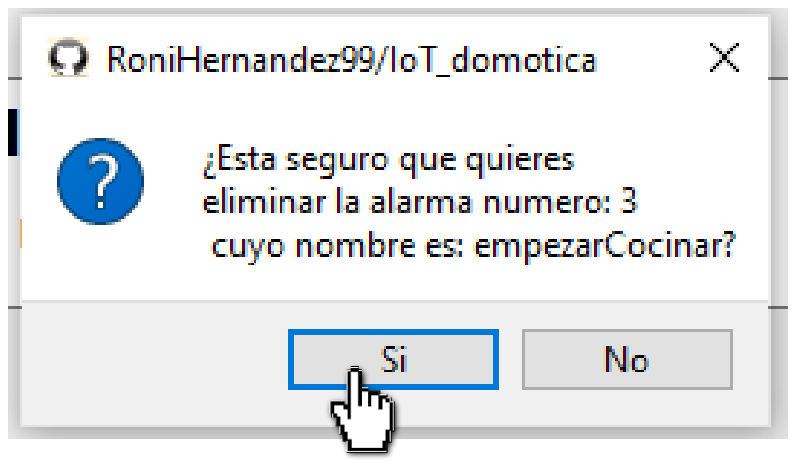
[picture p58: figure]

1. Dar clic sobre el tache que se encuentra en la esquina superior derecha de la alarma a eliminar | 2. Al hacer el paso uno, automáticamente se deberá desplegar un cuadro emergente que preguntará por última vez si en realidad se desea eliminar dicha alarma, se deberá dar clic izquierdo sobre la opción ‘Si’
| 4.Finalmente se podrá apreciar claramente que la alarma ‘empezarConcinar’ ya no se encontrara en el lugar donde se muestran las alarmas, lo cual significa que ha sido eliminada exitosamente.

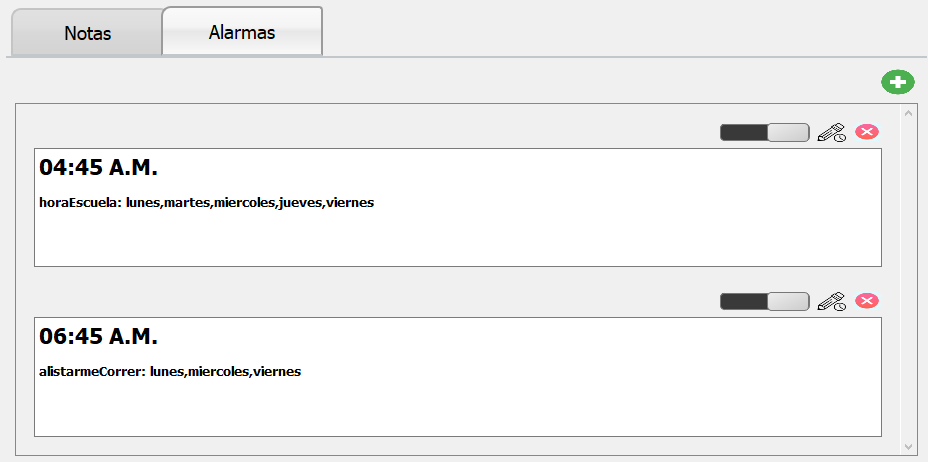
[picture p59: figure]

5.5 ¿CÓMO DESACTIVAR UNA ALARMA?

Si se deseara desactivar una alarma para que no suene sin necesidad de eliminarla, se deberá deslizar la barra deslizadora que se encuentra en su esquina superior derecha

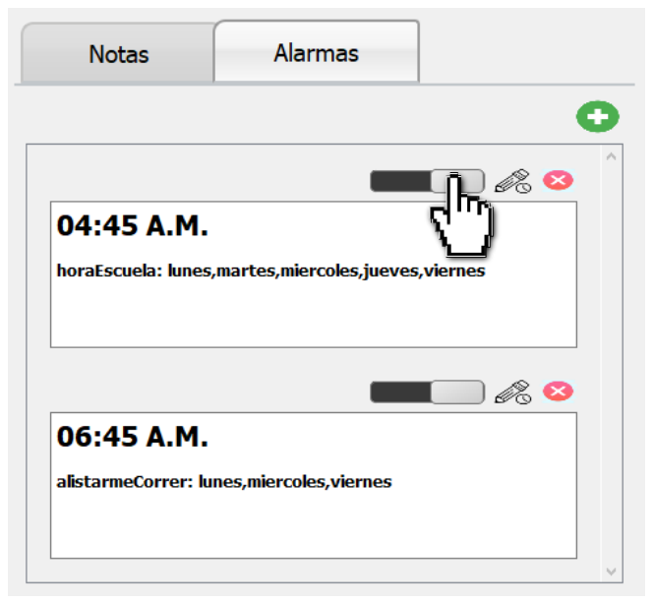
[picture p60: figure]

### 1. Alarma activada será cuando la barra deslizadora se

encuentra deslizada hacia la parte lateral derecha

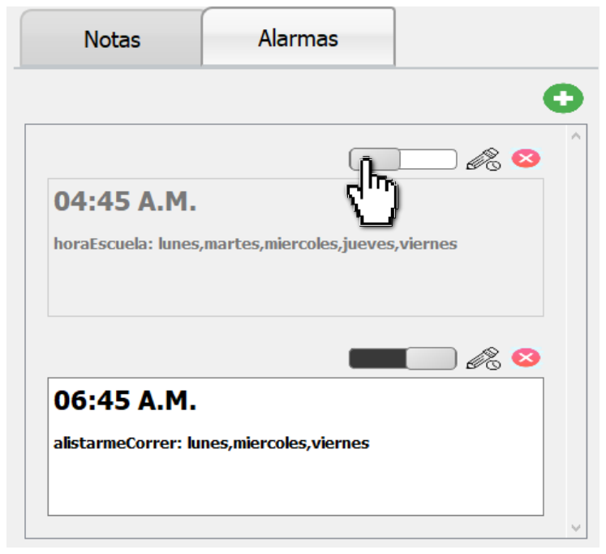
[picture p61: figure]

### 2. Alarma desactivada será cuando su barra deslizadora se encentre

deslizada hacia la parte lateral izquierda

5.6 ¿QUÉ PASARA CUANDO SEA LA HORA DE SONAR DE UNA ALARMA?

Se mostrará un cuadro emergente con únicamente dos datos de la alarma que esta sonando: la hora a la que debe sonar y el nombre de la alarma.

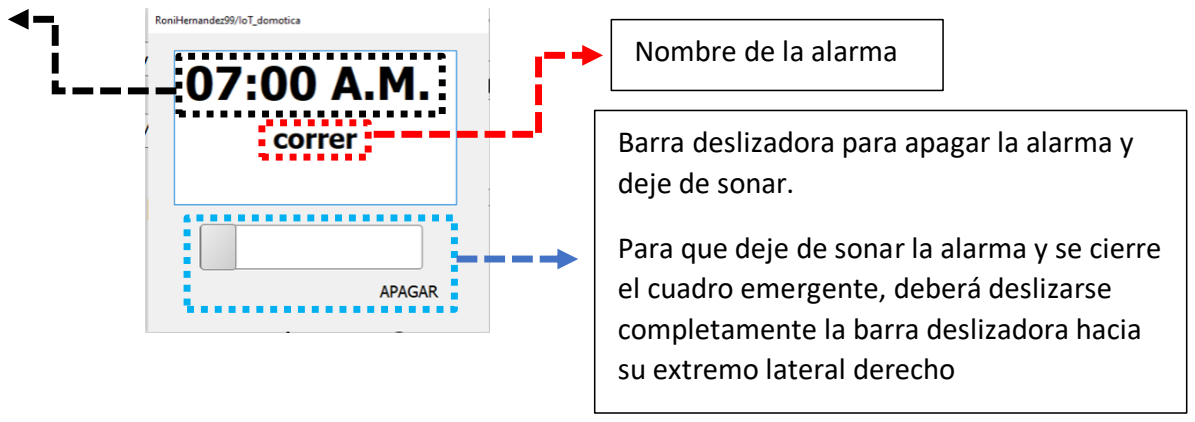
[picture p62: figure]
Nombre de la alarma; deje de sonar.; el cuadro emergente, deberá deslizarse completamente la barra deslizadora hacia su extremo lateral derecho

Ejemplo de cómo apagar una alarma que está sonando

### 1. Supongamos que se tiene una alarma programada para

levantarse a las 7 AM los sábado y domingos

### 2. Como ya son las 7: 00 AM, es hora de que se active automáticamente la

alarma, asi que eso sucede y se aparece una ventana emergente con la hora de la alarma y el nombre de esta debajo de la hora, para apagarla lo único que se deberá hacer será recorrer la barra deslizadora hasta el extremo lateral derecho de la barra y despues de eso automáticamente la ventana se cerrara y la alarma dejara de ejecutar la canción.

### 6. DETECTOR DE INCENDIOS

El sistema de domótica deberá estar siempre al pendiente de la aparición de fuego y si detecta alguna flama esta le deberá alertar al usuario a través de la GUI por medio de un sonido y un mensaje emergente.

A continuación, se adjuntará una captura de pantalla de cómo se deberá ver el mensaje de fuego detectado.

Es importante mencionar que cuando se detecta fuego:
- Se bloquea el control automático y manual de los objetos
- No se podrá hacer nada en la GUI
- Si una alarma tiene que sonar no sonara ya que la prioridad es alertar al usuario de la presencia del fuego.

### 7. DATOS DEL PROGRAMADOR

El sistema de domótica ofrecerá un apartado en donde el usuario pueda ver los contactos del programador asi como el repositorio de todo proyecto, lo único que se tendrá que hacer es dar clic izquierdo sobre el icono con signo de exclamación e inmediatamente se desplegara una ventana con dichos datos:

Hora a la que suena la alarma

Barra deslizadora para apagar la alarma y

Para que deje de sonar la alarma y se cierre

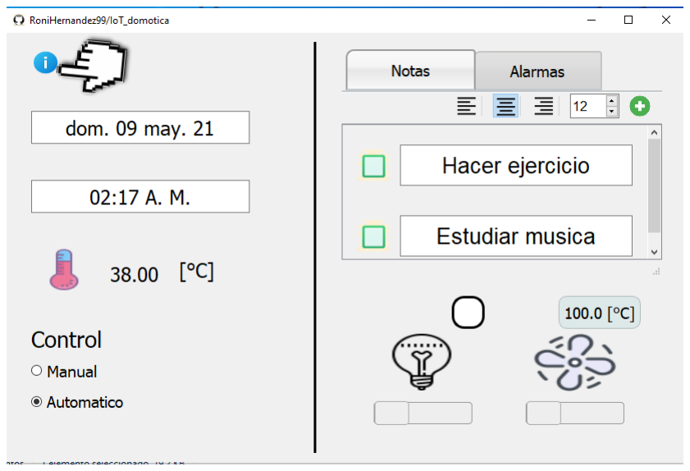
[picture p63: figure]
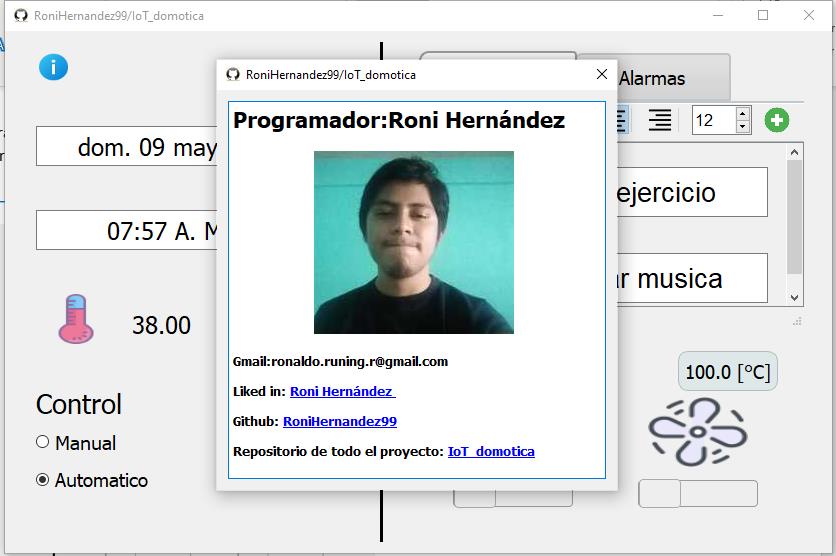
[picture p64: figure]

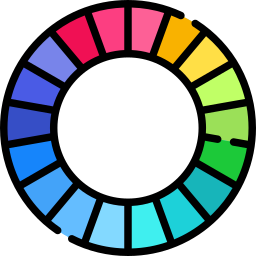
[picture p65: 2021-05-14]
GUI/IMAGENES/SISTEMA_CONTROL/rrueda1_blanco.png

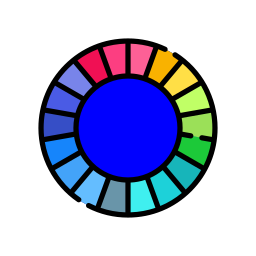
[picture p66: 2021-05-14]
GUI/IMAGENES/SISTEMA_CONTROL/rueda4_azul.png

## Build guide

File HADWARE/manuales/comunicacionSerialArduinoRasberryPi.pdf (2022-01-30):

# Comunicación en serie entre Raspberry Pi y Arduino

por Xukyo (https://www.aranacorp.com/es/author/xwadm/) | 27 Sep 2020 | Tutoriales (https://www.aranacorp.com/es/tutoriales/) | 0 Comentarios

Etiquetas: Arduino, (https://www.aranacorp.com/es/tag/arduino-es/) C/C++, (https://www.aranacorp.com/es/tag/cpp-es/) Comunicación serie, (https://www.aranacorp.com/es/tag/comunicacion-serie/) Python, (https://www.aranacorp.com/es/tag/python-es/) Raspberry PI (https://www.aranacorp.com/es/tag/raspberry-pi-es/)

5 (2)
En algunos proyectos, puede ser interesante establecer una comunicación en serie entre Raspberry Pi y Arduino. Así, es posible acoplar la potencia de computación y las interfaces inalámbricas del Raspberry Pi con las entradas/salidas y la colección de módulos Arduino. El primer ejemplo que viene a la mente es el uso de este sistema para la automatización del hogar en el que el Raspberry Pi albergará la interfaz de control e inteligencia y el Arduino servirá como un PLC que actuará sobre los componentes al nal de la cadena (luz, radiador, ventilador, sensores, etc.).

Veremos en este tutorial cómo congurar una comunicación en serie entre Raspberry Pi y Arduino a través del puerto USB. En este artículo utilizamos la tarjeta Arduino UNO pero puede ser adaptada a otros tipos de tarjetas con conexión en serie (Nano, Mega, Feather, EPS32, etc.).

Prerrequisito: Comunicación en serie con Arduino, (https://www.aranacorp.com/en/communicate-with-arduino/) Acceso remoto a Raspberry Pi con VNC (https://www.aranacorp.com/es/conexion-remota-a-raspberry-pi/)

## Hardware

Computadora
Arduino UNO
Raspberry Pi 3B+
USB A Macho / USB B Macho

## Diagrama de conexión

Para establecer una comunicación en serie entre Raspberry Pi y Arduino, simplemente conéctelos con un cable USB adecuado. En nuestro caso, usamos un Raspberry Pi 3B+ y un Arduino UNO. Así que necesitamos un cable USBA macho a USB B macho.

También es posible crear una comunicación en serie utilizando los pines Rx/Tx de ambos componentes. En este tutorial nos centraremos en la conexión USB.

Tx GPIO14(RPI) <-> Rx 0(Arduino)
Rx GPIO15(RPI) <-> Tx 1(Arduino)

Entradas recientes
Generación de sonidos con
una interfaz MIDI de
Arduino (https://www.aranacorp.com/es/generacion-de-sonidos-con-una-interfaz-midi-de-arduino/)
Gestión de un teclado
analógico 4×4 con Arduino (https://www.aranacorp.com/es/gestion-de-un-teclado-analogico-4x4-con-arduino/)
Uso del lector RFID PN532
con Arduino (https://www.aranacorp.com/es/uso-del-lector-rfid-pn532-con-arduino/)
Medición de la fuerza con
Arduino y el módulo HX711 (https://www.aranacorp.com/es/medicion-de-la-fuerza-con-arduino-y-el-modulo-hx711/)
Generar y cargar archivos
BIN para ESP32 (https://www.aranacorp.com/es/generar-y-cargar-archivos-bin-para-esp32/)

Newsletter

Prénom

Adresse E-mail

Inscrivez-moi !

Raspberry Pi (https://www.raspberrypi.org/)
Arduino (https://www.arduino.cc/)
Processing (https://processing.org/)
Fritzing (http://fritzing.org/home/)

Buscar

Inicio (https://www.aranacorp.com/es/inicio/) | Misión (https://www.aranacorp.com/es/mision/) | Tienda (https://www.aranacorp.com/es/tienda/) | Impresión 3D (https://www.aranacorp.com/es/impresion-3d/) | Blog 3 (https://www.aranacorp.com/es/blog-3/) | Cuenta (https://www.aranacorp.com/es/cuenta/) | Contacto (https://www.aranacorp.com/es/contacto/) | (https://www.aranacorp.com/es/carrito/)

GND (RPI) <-> GND(Arduino)

## Configuración del Raspberry Pi

Le recordamos que para poder usar su Raspberry Pi sin pantalla o teclado, la Conexión remota de VNC (https://www.aranacorp.com/es/conexion-remota-a-raspberry-pi/) debe ser congurada.

Para usar la interfaz en serie del Raspberry Pi, debe estar habilitada en el menú de conguración. Para ello, introduzca el siguiente comando en una terminal:

En el menú, seleccione «5 – Opciones de interfaz» y luego «Serie P6» y valide.

Una vez realizada la conexión, puede comprobar los dispositivos conectados al puerto serie tecleando el comando en la terminal:

El Raspberry Pi devuelve la lista de dispositivos conectados a los puertos USB.

Para encontrar el nombre del puerto en el que está conectado el Arduino, usamos el comando:

Este comando devuelve los mensajes del sistema relacionados con los puertos serie. Tenías que encontrar el nombre del puerto en los últimos mensajes. En nuestro caso el nombre del puerto es ttyACM0.

## Instalando el IDE de Arduino en Raspberry Pi

Para instalar el IDE de Arduino en el Raspberry Pi, lo mejor es pasar por la terminal. Sólo tienes que introducir las siguientes líneas de código:

Esto le permitirá programar el Arduino directamente desde el Raspberry Pi.

## Código

### Código Arduino

La biblioteca utilizada para la comunicación en serie en el lado de Arduino es la misma que la utilizada para comunicarse con el monitor de serie, la biblioteca Serial.h que conocemos bien. Asegúrate de que la velocidad de comunicación es la misma para ambos dispositivos (baudrate=9600), de lo contrario la comunicación no funcionará.

sudo raspi-config | Copy
lsusb | Copy

## pi@raspberrypi:~ $ lsusb Bus 001 Device 002: ID 2341:0043 Arduino SA Uno R3 (CDC ACM) Bus 001 Device 001: ID 1d6b:0002 Linux Foundation 2.0 root hub

Copy

dmesg | grep "tty" | Copy

pi@raspberrypi:~ $ dmesg | grep "tty" [ 0.000000] Kernel command line: coherent_pool=1M 8250.nr_uarts=1 bcm2708_fb.fbwidth=1824 bcm2708_fb.fbheight=984 bcm2708_fb.fbswap=1 smsc95xx.macaddr=B8:27:EB:23:CF:07 vc_mem.mem_base=0x1ec00000 vc_mem.mem_size=0x20000000 console=ttyS0,115200 console=tty1 root=/dev/mmcblk0p7 rootfstype=ext4 elevator=deadline fsck.repair=yes rootwait quiet splash plymouth.ignore-serial-consoles
[ | 0.000636] console [tty1] enabled
[ | 0.951553] 20201000.serial: ttyAMA0 at MMIO 0x20201000 (irq = 81,

## base_baud = 0) is a PL011 rev2

[ | 0.954393] console [ttyS0] disabled
[ | 0.954466] 20215040.serial: ttyS0 at MMIO 0x0 (irq = 53, base_baud

## = 31250000) is a 16550

[ | 0.954570] console [ttyS0] enabled
[ | 5.378641] systemd[1]: Created slice system-serial\x2dgetty.slice.

## [ 1455.402071] cdc_acm 1-1:1.0: ttyACM0: USB ACM device [ 1581.980257] cdc_acm 1-1:1.0: ttyACM0: USB ACM device

Copy

## mkdir ~/Applications cd ~/Applications wget https://downloads.arduino.cc/arduino-1.8.9-linuxarm.tar.xz tar xvJf arduino-1.8.9-linuxarm.tar.xz cd arduino-1.8.9/ ./install.sh rm ../arduino-1.8.9-linuxarm.tar.xz

Copy

String nom = "Arduino";
String msg;

## void setup() {

Serial.begin(9600);
}

## void loop() {

readSerialPort();

## if (msg != "") {

sendData();
}

Copy

### Código Python

En este tutorial, usaremos el lenguaje Python en el lado del Raspberry Pi. La biblioteca que se utiliza para gestionar la comunicación en serie es la biblioteca en serie.

### Resultado

El Raspberry Pi envía el comando «Hello Arduino» al Arduino, y el Arduino responde con su nombre y la orden recibida.

## Ejemplo práctico

Una vez establecida la comunicación entre Raspberry Pi y Arduino, lo interesante es conducir la E/S de Arduino y recuperar los valores del sensor. En este ejemplo, deniremos diferentes comandos:

uno para recuperar los valores de los sensores
uno para encender y apagar el LED en el pin 13

### Código Arduino

El Arduino, devuelve datos cuando recibe el comando «datos» y enciende y apaga el LED conectado al pin 13 según los comandos «led0» y «led1».

### Código Python

delay(500);
}

## void readSerialPort() {

msg = "";

## if (Serial.available()) {

delay(10);

1. #!/usr/bin/env python
2. # -*- coding: utf-8 -*-
3. # lsusb to check device name
4. #dmesg | grep "tty" to find port name
5.
6. import serial,time
7.
8.
9. if __name__ == '__main__':
10.
11. print('Running. Press CTRL-C to exit.')
12. with serial.Serial("/dev/ttyACM0", 9600, timeout=1) as arduino:
13. time.sleep(0.1) #wait for serial to open
14. if arduino.isOpen():
15. print("{} connected!".format(arduino.port))
16. try:
17. while True:
18. cmd=input("Enter command : ")
19. arduino.write(cmd.encode())
20. #time.sleep(0.1) #wait for arduino to answer
21. while arduino.inWaiting()==0: pass
22. if arduino.inWaiting()>0:
23. answer=arduino.readline()
24. print(answer)
25. arduino.flushInput() #remove data after reading
26. except KeyboardInterrupt:
27. print("KeyboardInterrupt has been caught.")

const int ledPin=13;
String nom = "Arduino";
String msg;

## void setup() {

Serial.begin(9600);
}

## void loop() {

readSerialPort();

## if (msg == "data") {

sendData();

## }else if(msg=="led0"){

digitalWrite(ledPin,LOW);
Serial.print(" Arduino set led to LOW");

## }else if(msg=="led1"){

digitalWrite(ledPin,HIGH); Serial.print(" Arduino set led to HIGH"); }

Copy

1. #!/usr/bin/env python
2. # -*- coding: utf-8 -*-
3. # lsusb to check device name
4. #dmesg | grep "tty" to find port name
5.
6. import serial,time
7.
8.
9. if __name__ == '__main__':
10. print('Running. Press CTRL-C to exit.')
11. with serial.Serial("/dev/ttyACM0", 9600, timeout=1) as arduino:
12. time.sleep(0.1) #wait for serial to open
13. if arduino.isOpen():

Una vez que los dos códigos han sido cargados y lanzados, se puede observar que cuando se introduce el
comando «datos» en la terminal, Arduino devuelve muchos bytes que contienen los valores del sensor. Es posible separar esta respuesta en una lista usando la función split() y el carácter «x» y así recuperar los valores del sensor y el estado del led. Gracias a este código, podemos controlar el estado del LED del pin 13.

Modicando este código, podrás conducir y observar cualquier entrada/salida de Arduino en el Raspberry Pi.

## Application

Crear una interfaz gráca de usuario (GUI) bajo el Raspberry Pi para manejar un Arduino y recuperar los valores del sensor

## Sources

Librería pySerial (https://pyserial.readthedocs.io/en/latest/pyserial_api.html)
Comunicación en serie con Arduino (https://www.aranacorp.com/es/comunicarse-con-arduino/) Acceso remoto a Raspberry Pi con VNC (https://www.aranacorp.com/es/conexion-remota-a-raspberry-pi/)

## ¿De cuánta utilidad te ha parecido este contenido?

¡Haz clic en una estrella para puntuar!

Promedio de puntuación 5 / 5. Recuento de votos: 2

### Enviar comentario

Tu dirección de correo electrónico no será publicada. Los campos obligatorios están marcados con *

Nombre *

Correo electrónico *

Web

Comentario

14. print("{} connected!".format(arduino.port)) 15. try: 16. while True: 17. cmd=input("Enter command (data,led0 or led1): ")
18. arduino.write(cmd.encode()) 19. #time.sleep(0.1) #wait for arduino to answer 20. 21. while arduino.inWaiting()==0: pass 22. if arduino.inWaiting()>0: 23. answer=str(arduino.readline()) 24. print("---> {}".format(answer)) 25. if cmd=="data": 26. dataList=answer.split("x") 27. print("led state : {}".format(dataList[0])) 28. print("Analog input A0 : {}".format(dataList[1])) 29. print("Analog input A1: {}".format(dataList[2]))

30

Encuentre otros tutoriales y ejemplos en el generador de código automático

## Arquitecto de Código (https://www.aranacorp.com/es/arquitecto-de-codigo/)

## Enviar comentario

Misión (https://www.aranacorp.com/es/mision/) | Raspberry Pi (https://www.raspberrypi.org/) | Proyectos (https://www.aranacorp.com/es/proyectos/)

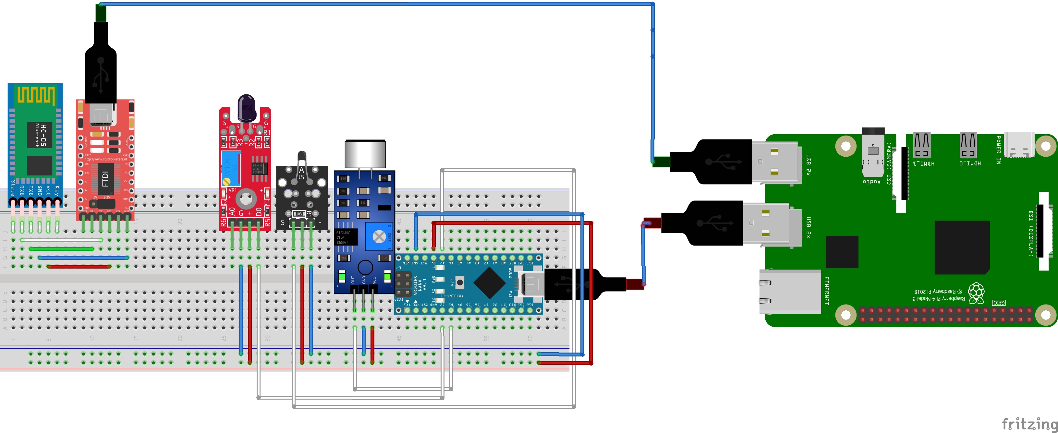
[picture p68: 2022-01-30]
recursos_readme/ENSAMBLE/circuito_1.jpg

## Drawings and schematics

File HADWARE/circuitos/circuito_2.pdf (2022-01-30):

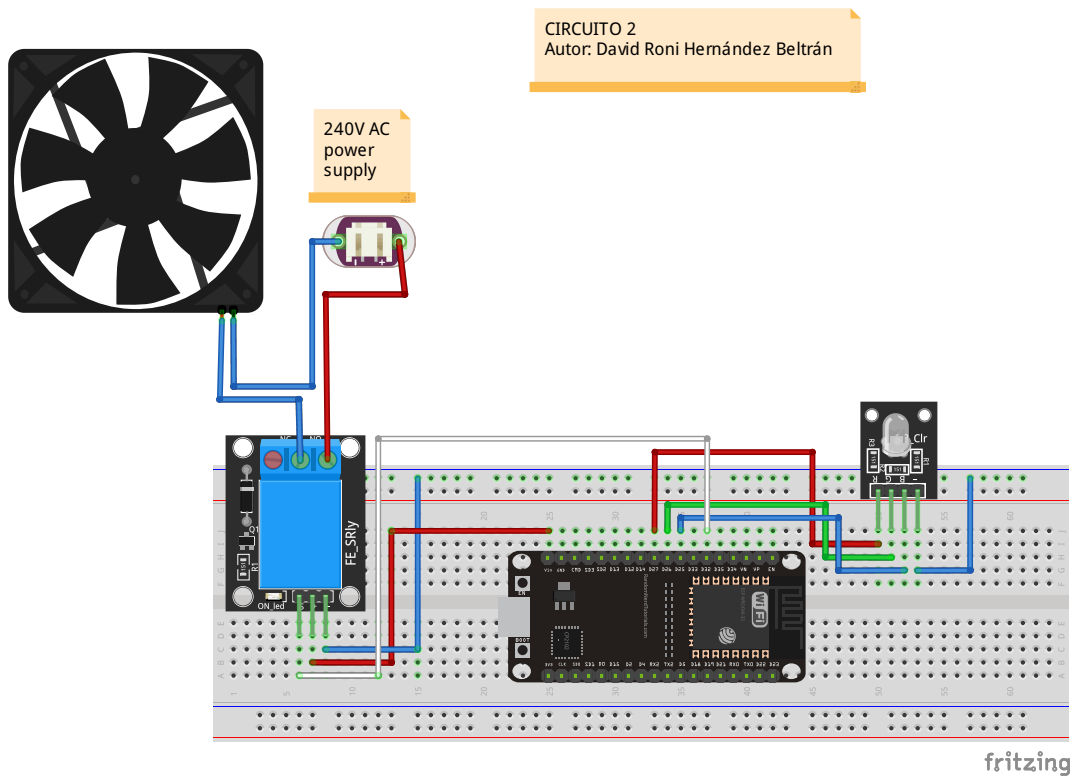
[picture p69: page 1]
240V AC power supply

CIRCUITO 2
Autor: David Roni Hernández Beltrán

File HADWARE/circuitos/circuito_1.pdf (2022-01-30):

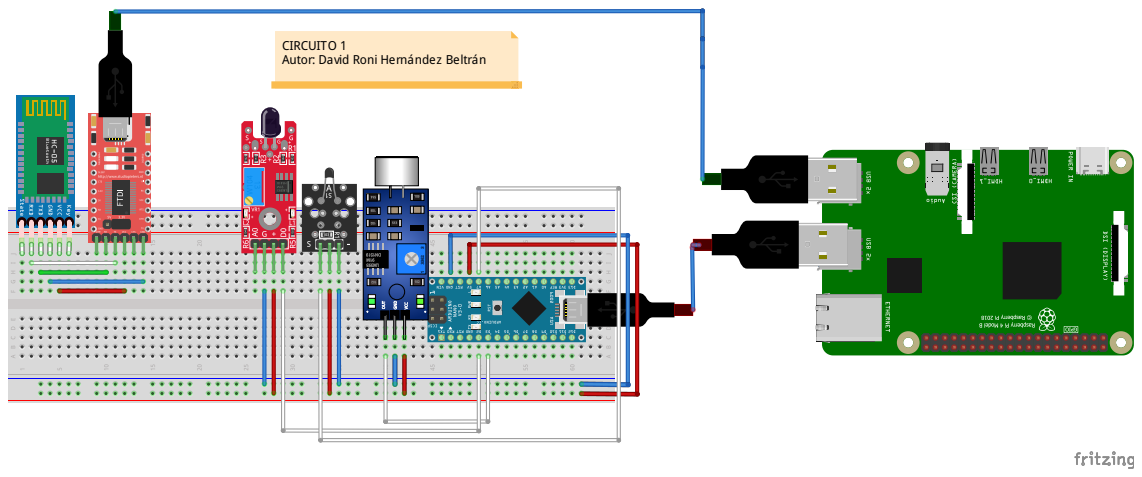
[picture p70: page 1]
vid; elt r

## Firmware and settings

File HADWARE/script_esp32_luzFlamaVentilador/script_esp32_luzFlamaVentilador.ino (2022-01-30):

///////////////////////////////////////////////////////////////////////////////////////////////////////////////////////////////////////////////////////////////////////
//  INICIO DE CODIGO:
///////////////////////////////////////////////////////////////////////////////////////////////////////////////////////////////////////////////////////////////////////
#include <BluetoothSerial.h>
#include "Led_sieteColor.h"

// ESTADOS DE LOS SENSORES...
#define APAGAR 0
#define PRENDER 1
#define CAMBIAR_COLOR_FOCO 2
#define ORDEN_ATENDIDA 5

//ID DE LOS SENSORES...
#define VENTILADOR  10
#define FOCO  11

//CONSTANTES...
const char CHAR_SEGURIDAD='_';  
const char CHAR_NO_SEGURIDAD='+';
const byte PIN_VENTILADOR=32; //D32

// Dato de tipo puntero a funcion que retornaran unas funciones...
typedef void (*ordenUnSensor)(int);


//VARIABLES GLOBALES...
BluetoothSerial SerialBT;
uint8_t address1[6] = {0x98, 0xD3, 0x36, 0x81, 0x13, 0x70}; // HC-05
String name = "blutu_roni";
char *pin = "1234"; 
bool connected;
Led_sieteColor G_focoDelCuarto(27,26,25,false);

void setup() {
  Serial.begin(115200);
  SerialBT.begin("Cuarto_luzFlamaVentilador", true);
  SerialBT.setPin(pin);
  Serial.println("The device started in master mode, make sure remote BT device is on!");
  // connect(address) is fast (upto 10 secs max), connect(name) is slow (upto 30 secs max) as it needs
  // to resolve name to address first, but it allows to connect to different devices with the same name.
  // Set CoreDebugLevel to Info to view devices bluetooth address and device names
  connected = SerialBT.connect(name);
  //connected = SerialBT.connect(address1);
  
  if(connected) {
    Serial.println("Connected Succesfully!");
  } else {
    while(!SerialBT.connected(10000)) {
    Serial.println("Failed to connect. Make sure remote device is available and in range, then restart app.");
    }
  }
  
  // disconnect() may take upto 10 secs max
  //if (SerialBT.disconnect()) {
  //  Serial.println("Disconnected Succesfully!");
  //}
  
  // this would reconnect to the name(will use address, if resolved) or address used with connect(name/address).
  //SerialBT.connect();


  pinMode(PIN_VENTILADOR,OUTPUT); 

}

void loop() {
  char charTerminaMensaje;
  byte idSensor,idOrdenRealizar; 
  //void (*ordenRealizar)(int); //puntero a funcion...
  ordenUnSensor ordenRealizar; //puntero a funcion..
  int param_1;
  char charBufer; 
  String respuesta;

  
  while(true){
      charTerminaMensaje=CHAR_NO_SEGURIDAD; //le asignamos un char diferente al CHAR_SEGURIDAD
      charBufer=CHAR_NO_SEGURIDAD; 
      respuesta="";
      param_1=0;
      
      while( charBufer!=CHAR_SEGURIDAD   ){
        charBufer= char( SerialBT.read() );
        Serial.print(charBufer);
        delay(100);
      }
      Serial.println("ENTRAMOS AL PARSEint: ");
      idSensor=SerialBT.parseInt();
      Serial.println("SALIMOS DEL PARSEint: ");
      SerialBT.read();//con esto eliminamos al separador(en este caso a la ',' ) del buffer
  
      Serial.println("ENTRAMOS AL PARSEint: ");
      idOrdenRealizar=SerialBT.parseInt();//puede ser cero(apagar) o uno(prender)
      Serial.println("SALIMOS DEL PARSEint: ");
      
      Serial.print("ID SENSOR: ");Serial.println(idSensor);
      Serial.print("ID ORDEN: ");Serial.println(idOrdenRealizar);
  
      switch(idSensor){
          case FOCO:
            ordenRealizar=foco_dameOrden(idOrdenRealizar,&param_1);
            break;
                   
         case VENTILADOR:
            ordenRealizar=ventilador_dameOrden(idOrdenRealizar);
          break;
          
         default:
             break;  
    }//fin del swith...
        
    charTerminaMensaje=char(SerialBT.read());
    Serial.print("FIN MENSAJE: ");Serial.println(charTerminaMensaje);
    if(charTerminaMensaje==CHAR_SEGURIDAD){
        Serial.println("EJECUTANDO ORDEN: ");
        ordenRealizar(param_1); 
        respuesta=empaquetarMensaje(String(ORDEN_ATENDIDA));
        SerialBT.println(respuesta); //le notificamos que ya fue realizado la orden
    }
    
  }          
}

  
////////////////////////////////////////////////////////////////////////////////////////////////////////////////////////////////////////////////////////
// MENUS DE CADA SENSOR...
////////////////////////////////////////////////////////////////////////////////////////////////////////////////////////////////////////////////////////

ordenUnSensor foco_dameOrden(int idOrden,int *puntero_param1){
    int param_1;
    //void (*ordenRealizar)(int); //puntero a funcion...
    ordenUnSensor ordenRealizar; //puntero a funcion...
    switch(idOrden){
     case PRENDER:
        ordenRealizar=&prenderFoco;
        break;
     case APAGAR:
        ordenRealizar=&apagarFoco;
        break;
     case CAMBIAR_COLOR_FOCO:
        ordenRealizar=&cambiarColorFoco;
        Serial.read();//con esto eliminamos al separador(en este caso a la ',' ) del buffer
        param_1=SerialBT.parseInt(); //esto representara el color del foco
        *puntero_param1=param_1;
        break;
     default:
       break;
   }
   return ordenRealizar; 
}


ordenUnSensor ventilador_dameOrden(int idOrden){
    //void (*ordenRealizar)(int); //puntero a funcion...
    ordenUnSensor ordenRealizar; //puntero a funcion...
    switch(idOrden){
        case PRENDER:
          ordenRealizar=&prenderVentilador;
          break;
        case APAGAR:
          ordenRealizar=&apagarVentilador;
          break;
        default:
         break;
   }
   return ordenRealizar; 
}

////////////////////////////////////////////////////////////////////////////////////////////////////////////////////////////////////////////////////////
//  COMPORTAMIENTOS DE LOS DIFERENTES ESTADOS DE MIS CENSORES...
////////////////////////////////////////////////////////////////////////////////////////////////////////////////////////////////////////////////////////

void prenderFoco(int _noImporta ){
   G_focoDelCuarto.prender();
}

void apagarFoco(int _noImporta ){
   G_focoDelCuarto.apagar();
}

void cambiarColorFoco(int idColor){
  G_focoDelCuarto.cambiarColor(idColor);
}

void prenderVentilador(int _noImporta ){
  digitalWrite(PIN_VENTILADOR,HIGH);  
}

void apagarVentilador(int _noImporta ){
 digitalWrite(PIN_VENTILADOR,LOW);     
}


String empaquetarMensaje(String mensaje){
  mensaje=CHAR_SEGURIDAD+mensaje+CHAR_SEGURIDAD;
  return mensaje;
}

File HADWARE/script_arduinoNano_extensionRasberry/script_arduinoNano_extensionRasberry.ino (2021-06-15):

#include <math.h>

//Variables globales:
bool G_sonidoDetectado=false;
bool G_flamaDetectada=false;
long G_tiempo=500;

//Estados de los sensores:
#define TEMPERATURA "1"
#define SONIDO_DETECTADO "2"
#define FUEGO_DETECTADO "3"
#define FUEGO_APAGADO "4"
//Constantes...
const String CHAR_SEGURIDAD="_";
const String SEP_ENTRE_DATOS=",";

//Pines...
#define PIN_MICROFONO 3
#define PIN_SENSOR_FLAMA 2
#define PIN_SENSOR_TEMPERATURA A7

void setup() {
 Serial.begin(9600);
 attachInterrupt(digitalPinToInterrupt(PIN_MICROFONO),sonidoDetectado,RISING);
 attachInterrupt(digitalPinToInterrupt(PIN_SENSOR_FLAMA),flamaDetectada,RISING); 
  
}
void loop() {
  char respuesta;
  String mensaje;

  while(true){
    if (!G_sonidoDetectado && !G_flamaDetectada ){
       mensaje= (TEMPERATURA+SEP_ENTRE_DATOS);
       mensaje+= String(Thermister(analogRead(PIN_SENSOR_TEMPERATURA)));  
       mensaje=empaquetarMensaje( mensaje ); 
            
    }else if(G_sonidoDetectado){
      G_sonidoDetectado=false;
      G_tiempo=750;
      mensaje=empaquetarMensaje( SONIDO_DETECTADO );
    }else{
      actuar_fuegoDetectado();
      continue;
    }
   Serial.println(mensaje);
   delay(G_tiempo); 
 }

}


double Thermister(int RawADC) {
 double Temp;
 Temp = log(((10240000/RawADC) - 10000));
 Temp = 1 / (0.001129148 + (0.000234125 + (0.0000000876741 * Temp * Temp ))* Temp );
 Temp = Temp - 273.15; // Convert Kelvin to Celcius
 return Temp;
}

void sonidoDetectado(){
  G_sonidoDetectado=true;
  G_tiempo=0;
}

void flamaDetectada(){
  G_flamaDetectada= true;
}


String empaquetarMensaje(String mensaje){
  mensaje=CHAR_SEGURIDAD+mensaje+CHAR_SEGURIDAD;
  return mensaje;
}


// DESACTIVAR Y ACTIVAR INTERRUPCCIONES...
//https://community.particle.io/t/nointerrupts/47264
void actuar_fuegoDetectado(){
  String mensaje;
  int MAX_ESPERA=10;
  int c=0; //contador de esperas
  //desactivamos la interrupccion del micronfono
  detachInterrupt(digitalPinToInterrupt(PIN_MICROFONO)) ;
  //vaciamos todo nuestro buffer
  while(Serial.available()){  Serial.read();  } 
  //medimos mientras dure el fuego cada 500 [ms]
  while(true){       
    delay(500);
    //Serial.print(" FUEGO... ");
    G_flamaDetectada =digitalRead(PIN_SENSOR_FLAMA);
    if (!G_flamaDetectada){ //la flama ya no es detectada...
      mensaje=empaquetarMensaje( FUEGO_APAGADO );
      Serial.println(mensaje) ;
      delay(250);
      c+=1;
      if( Serial.available() || c >MAX_ESPERA){//recibimos alguna respuesta...
        G_flamaDetectada=false;
        break;
      }
   }else{//la flama sigue siendo detectada...
      mensaje=empaquetarMensaje( FUEGO_DETECTADO );
      Serial.println(mensaje);
    }
    
 }
 attachInterrupt(digitalPinToInterrupt(PIN_MICROFONO),sonidoDetectado,RISING);
}

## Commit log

2021-03-06 Realice el primer bosquejo del diseÃo de la pantalla principal(archivo 'CUERPO/DISENO/main_dise.py') del sistema de domotica,para ello descargue algunas imagenes que necesite, posteriormente el scrip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
2021-03-07 Asigne un nombre clave a cada elemeno clave('buttom','label',etc) del widget del diseno de la ventana principal ('CUERPO/DISENO/main_dise.py'), tambien cree el diseno de la ventana emergente cuyo nom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
2021-03-08 Agrege una ventana de dialogo para configurar la temperatura a la cual se va a prender el ventilador, para configurar el color con el foco prendera y para agendar alarmas, por ultimo modifique un poc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
2021-03-09 Para poder editar las alarmas de una manera mas comoda crea el diseno de una ventana emergente que se aparecera cada vez que quieras editar una alarma, aparte hice mas grandes los sliders de la widge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
2021-03-12 Organice la programacion respectiva de la GUI y el SOFWARE, en cuanto respecta al directorio del SOFWARE en el estuve trabajando con unos sencillos scripts cuyo proposito fue probar el comportamiento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
2021-03-15 Realice unas pruebas del sensor detector de flama, por tal motivo probe un script de arduino cuyo nombre es 'detectoFlama' y se encuentra en el apartado 'SOFWARE/SENSORES'.Una vez finalizado la prueb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
2021-03-15 Trabaje en los scripts logicos cuyos nombres son 'configLed.py' y 'configVenti.py' los cuales se encuentran en el apartado 'CUERPO/LOGICA', las nuevas modificaciones en este script permitieron la com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
2021-03-18 Desarrolle el script del esp-32 que me permite comunicarme corectamente con un 'Modulo de bluetooth HC-05', en este script inclui la funcion del ventilador, el foco que cambia de color, y el sensor q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
2021-03-18 Idee una primer solucion de como sincronizar la comunicacion de la GUI y el ESP-32 atravez del protocolo de comunicacion Blueetooth, hasta el momento funciono bien, todo se sincroniza bien, para logr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
2021-03-20 El motivo de estas modificaciones fue para que el 'sensorFlama' sense desde el arduino 'Nano' y no desde el 'esp-32' ya que esto facilita bastante la programacion y lo hace mucho mas claro, debido a 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
    [arduinoExtension.py, bluetoothSerial.py, configVenti.py]
2021-03-21 Una vez lograda una mejor organizacion de la comunicacion entre la 'rasberry' el 'esp-32' y el 'arduino nano', prosegui a organizar de mejor manera la inerfaz grafica para ir agregando la seccion de 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
2021-03-22 En esta actualizacion me enfoque a hacer el diseno principal adaptable a un tamano mas grande por tal motivo modifique el archivo cuyo nombre es: 'main_dise.py' y 'main_dise.ui' y por cualquier cosa 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
2021-03-23 Limpie el codigo principal cuyo nombre es: 'main.py' de tal manera que comente algunas lineas de codigo y tambien trate de ahorrar algunas variables sin perjudicar el entendimiento de mi codigo. Tamb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
2021-03-27 En esta actualizacion tuve avances enfocados a la creacion de alarmas, asi como el respaldo de ellas a traves de sqlite3 y sobre todo organizacion en los scripts de alarmas, con esta actualizacion mi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
    Finalmente tambien trabaje con la hora a traves de un 'Qtimer' que se
    encunetra en el script principal.
2021-03-29 En esta modificacion me concentre en el permitir tener dos listas de reproduccion, una con canciones 'default' que ya vendran dentro de la aplicacion, y otra para canciones que el usuario quiera agre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
2021-04-03 Cambie de ubicacion y el nombre de la base de datos de alarmas Implemente los cuadros de dialogo para que sus respuestas esten en español Hice el cuadro de dialogo que avisara cuando una cancion supe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
2021-04-03 Agregue en metodo en la clase 'Alarma' con la finalidad de mostrar la hora de alarma de una forma mas amigable Cree restricciones a la hora de crear alarmas,las cuales son las siguientes: no permito 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
2021-04-09 En esta ultima modificacion me concentre en lograr que funcionen las alarmas registradas, de tal manera que cuando es la hora de sonar de una alarma el sistema ahora avisara y tocara la cancion elegi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
2021-04-12 Agrege los sonidos que se emitiran en funcion de los estados de las alarmas, es decir cuando si se programo una alarma para despertar se escuchara un sonido especial para dicha alarma, y asi mismo su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
2021-04-19 En este modificacion me concentre en respaldar los deberes que el usuario pone, ya que antes cuando se cerraba la aplicacion y se volvia a abrir, estos no se guardaban, la metologia que emplee para e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
2021-04-22 En esta confirmacion me enfoque en varios puntos, los cuales fueron los siguientes: A) Que cada dia que pase se registre y se pueda visualizar dicho cambio en el timeEdit de la GUI principal B) Que t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
2021-04-23 En esta confirmacion modifique el script cuyo nombre es 'main.py' y 'mainFast.py' de tal manera que mi programa ya puede resguardar la temperatura a la cual el usuario quiere que se prenda el ventila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
2021-04-23 Movi el script de recursos en la direccion donde se encuentra el script principal, debido a que ahi es mas practico acceder a el, aparte de que se entiende mejor la organizacion, finalmente prosegui 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
2021-04-23 Se realizo modificaciones en el script 'recursos.py' y en el script 'mainFast.py' y 'main.py' con la finalidad de lograr que no perjudique el lugar desde donde llames el programa, es decir si lo llam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
2021-05-14 En esta modificacion empece a comentar algunas partes de mi codigo y al mismo tiempo aproveche para cambiar el diseño de mi programa a un mas inovador, dicho cambio requirio modificar varias seccione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
2021-05-14 En esta modificacion me concentre en corregir los pequeños detalles que en el sistema operativo linux distribucion debian aparecieron en cuanto respecta al diseño de las interfaz grafica
2021-05-24 En esta modificación agregue unas pequeñas variaciones al diseno, y me enfoque a comentar, documentar y aplicar loggin a los scrits: A) itemDeber.py B) SeccionDeberes.py Con lo anterior mencionado el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
2021-06-01 Corregi el siguientes errores detectados: A) Cuando se agregaba una cancion en la lista de reproduccion y luego se eliminaba dicha cancion el programa se detenia. B) Si no se daba clic izquierdo ante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
2022-01-30 En esta confirmación me encargue de terminar de documentar todo mi proyecto, lo cual significo que genere los diagramas eléctricos y realice algunas grabaciones de su funcionamiento y aparte ensene c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
    [circuito_1.fzz, circuito_2.fzz]
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
